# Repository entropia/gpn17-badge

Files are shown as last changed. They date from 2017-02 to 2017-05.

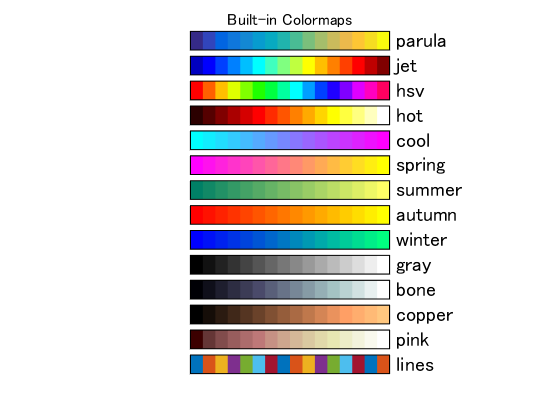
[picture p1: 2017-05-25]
examples/mandel/colormapGenerator/screenshot.jpg

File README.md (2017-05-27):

# GPN17 Badge
GPN Badge (Gulasch Push Notifications)

HowTo SetUp arduino:
- Install the newest arduino Version (tested with 1.8.2) from the [Arduino website](http://www.arduino.cc/en/main/software).
- Start Arduino and open Preferences window.
- Enter ```https://rawgit.com/entropia/gpn17-badge/master/arduino/package_gpnbadge_index.json``` into *Additional Board Manager URLs* field. You can add multiple URLs, separating them with commas.
- Open Boards Manager from Tools > Board menu and install *gpnbadge* platform (and don't forget to select the GPN Badge board from Tools > Board menu after installation).

To use multirom ability, please add 
```#include "rboot.h"```
to each of your sketches. This replaces the cache function in the libmain.a
Please note: For the moment, rboot is configured as following:

- 4 ROMs / 1MB each
- default boot ROM: 1 
- GPIO boot ROM: 0 (usually the ROM select app)

The GPIO boot is initialised by pulling GPIO16 high at POR. This is the same as pressing the center joystick of the GPN Badge at poweron. Other ROMs can be selected by using the rboot config library.

The patched arduino-esp8266 contains all tools for creating the usual eboot arduino roms, as well as rboot roms.
For this, in addition to esptool also Richard Burtons esptool2 ist downloaded and installed.

Have fun!

## In need for a example ROM?
Look for the "Sensors"-example.

## Beschreibung
Teilnehmerbadge mit vielen Funktionen für die GPN 17.

## Grafik-lib
https://github.com/entropia/Adafruit-GFX-Library

## Display-lib
https://github.com/antonxy/TFT_ILI9163C

By default this lib allocates a framebuffer.
If your rom is unstable because of little ram you can disable the framebuffer by commenting out `#define FRAMEBUFFER` in the `TFT_ILI9163C.h` file.
This should especially be done for the default rom.

## Arduino-lib
https://github.com/entropia/gpn17-badge-arduinolib

## UI-lib
https://github.com/entropia/gpn17-badge-ui

## Infrared-lib
https://github.com/markszabo/IRremoteESP8266

## Neopixel-lib
https://github.com/adafruit/Adafruit_NeoPixel

## Notification Server
https://github.com/entropia/gpn17-badge-notification-server

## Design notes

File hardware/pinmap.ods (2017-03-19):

GPIO | Function | V1.0 | V1.1 | V2.0
0 |  | BOOT / LCD DC | BOOT / LCD | BOOT / LCD DC
1 |  | UART TX | UART TX | UART TX
2 |  | WS2813 | USB DN | USB DN
3 |  | UART RX | UART RX | UART RX
4 |  | USB DN | WS2813 | WS2813
5 |  | USB DP | USB DP | USB DP
9 |  | LATCH | LATCH | I2C SDA
10 |  | LCD PWM | LCD PWM | I2C SCL
12 |  | SPI MISO | SPI MISO | SPI MISO (needed?) / BNO
13 |  | SPI MOSI | SPI MOSI | SPI MOSI
14 |  | SCP CLK | SPI CLK | SPI CLK
15 |  | LCD CS | LCD CS | LCD CS
16 |  | MPU6500 CS | MPU6500 CS | ROM Select
PCA9571
0 | MUX0
1 | MUX1
2 | MUX2
3 | VIBRATOR
4 | MQ3_en
5 | LCD_en
6 | Infrared_en
7

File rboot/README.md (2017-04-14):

GPN-Badge Port
--------------------------------------------------

HowTo:

1. Install arduino esp8266 IDE

2. Edit board.txt: Add attached config

3. Add LD scripts to
~/.arduino15/packages/esp8266/hardware/esp8266/2.3.0/tools/sdk/ld

4. Compile (don't upload) the sketch in the arduino IDE.
(to use bigflash, add both the big-flash.c as well as the rboot.h to the sketch)

5. Generate rboot compatible ROM
esptool2 -bin -boot2 /tmp/arduino_build_xxxxxx/sketch.ino.elf rom.bin .text .data .rodata

6. build rboot.bin (or use precompiled rboot.bin in /firmware)

7. flashing
esptool.py --port /dev/ttyUSB0 -b 921600 write_flash --flash_size 4MB --flash_mode dio 0x0 rboot.bin 0x02000 rom0.bin 0x102000 rom1.bin 0x202000 rom2.bin 0x302000 rom3.bin

rBoot - An open source boot loader for the ESP8266
--------------------------------------------------
by Richard A Burton, richardaburton@gmail.com
http://richard.burtons.org/

rBoot is designed to be a flexible open source boot loader, a replacement for
the binary blob supplied with the SDK. It has the following advantages over the
Espressif loader:

  - Open source (written in C).
  - Supports up to 256 roms.
  - Roms can be variable size.
  - Able to test multiple roms to find a valid backup (without resetting).
  - Flash layout can be changed on the fly (with care and appropriately linked
    rom images).
  - GPIO support for rom selection.
  - Wastes no stack space (SDK boot loader uses 144 bytes).
  - Documented config structure to allow easy editing from user code.
  - Can validate .irom0.text section with checksum.
  - Temporary next-boot rom selection.

Limitations
-----------
The ESP8266 can only map 8Mbits (1MB) of flash to memory, but which 8Mbits to
map is selectable. This allows individual roms to be up to 1MB in size, so long
as they do not straddle an 8Mbit boundary on the flash. This means you could
have four 1MB roms or 8 512KB roms on a 32Mbit flash (such as on the ESP-12), or
a combination. Note, however, that you could not have, for example, a 512KB rom
followed immediately by a 1MB rom because the 2nd rom would then straddle an
8MBit boundary. By default support for using more than the first 8Mbit of the
flash is disabled, because it requires several steps to get it working. See
below for instructions.

Building
--------
A Makefile is included, which should work with the gcc xtensa cross compiler.
There are two source files, the first is compiled and included as data in the
second. When run this code is copied to memory and executed (there is a good
reason for this, see my blog for an explanation). The make file will handle this
for you, but you'll need my esptool2 (see github).

To use the Makefile set `SDK_BASE` to point to the root of the Espressif SDK and
either set `XTENSA_BINDIR` to the gcc xtensa bin directory or include it in your
`PATH`. These can be set as environment variables or by editing the Makefile.

Two small assembler stub functions allow the bootloader to launch the user code
without reserving any space on the stack (while the SDK boot loader uses 144
bytes). This compiles fine with GCC, but if you use another compiler and it
will not compile/work for you then uncomment the `#define BOOT_NO_ASM` in `rboot.h`
to use a C version of these functions (this uses 32 bytes).

Tested with SDK v1.3 and GCC v4.8.2.

Installation
------------
Simply write rboot.bin to the first sector of the flash. Remember to set your
flash size correctly with your chosen flash tool (e.g. for esptool.py use the
`-fs` option). When run rBoot will create it's own config at the start of sector
two for a simple two rom system. You can can then write your two roms to flash
addresses `0x2000` and (half chip size + `0x2000`). E.g. for 8Mbit flash:
  `esptool.py write_flash -fs 8m 0x0000 rboot.bin 0x2000 user1.bin 0x82000 user2.bin`

Note: your device may need other options specified. E.g. The nodemcu devkit v1.0
(commonly, but incorrectly, sold as v2) also needs the `-fm dio` option.

For more interesting rom layouts you'll need to write an rBoot config sector
manually, see next step.

The two testload bin files can be flashed in place of normal user roms for
testing rBoot. You do not need these for normal use.

rBoot Config
------------

	typedef struct {
		uint8 magic;           // our magic
		uint8 version;         // config struct version
		uint8 mode;            // boot loader mode
		uint8 current_rom;     // currently selected rom
		uint8 gpio_rom;        // rom to use for gpio boot
		uint8 count;           // number of roms in use
		uint8 unused[2];       // padding
		uint32 roms[MAX_ROMS]; // flash addresses of the roms
	#ifdef BOOT_CONFIG_CHKSUM
		uint8 chksum;          // boot config chksum
	#endif
	} rboot_config;

Write a config structure as above to address `0x1000` on the flash. If you want
more than 4 roms (default) just increase MAX_ROMS when you compile rBoot.
Think about how you intend to layout your flash before you start!
Rom addresses must be sector aligned i.e start on a multiple of 4096.

  - `magic` should have value `0xe1` (defined as `BOOT_CONFIG_MAGIC`).
  - `version` is used in case the config structure changes after deployment. It is
    defined as `0x01` (`BOOT_CONFIG_VERSION`). I don't intend to increase this, but
    you should if you choose to reflash the bootloader after deployment and
    the config structure has changed.
  - `mode` can be `0x00` (`MODE_STANDARD`) or `0x01` (`MODE_GPIO_ROM`). See below for an
    explanation of `MODE_GPIO_ROM`. There is also an optional extra mode flag `0x04`
    (`MODE_GPIO_ERASES_SDKCONFIG`), see below for details.
  - `current_rom` is the rom to boot, numbered `0` to `count-1`.
  - `gpio_rom` is the rom to boot when the GPIO is triggered at boot.
  - `count` is the number of roms available (may be less than `MAX_ROMS`, but not
    more).
  - `unused[2]` is padding so the `uint32` rom addresses are 4 bytes aligned.
  - `roms` is the array of flash address for the roms. The default generated
    config will contain two entries: `0x00002000` and `0x00082000`.
  - `chksum` (if enabled, not by deafult) should be the xor of `0xef` followed by
    each of the bytes of the config structure up to (but obviously not
    including) the chksum byte itself.

Default config
--------------
A default config sector will be created on boot if one does not exists, or if an
existing config is corrupted, and the default rom will be set to rom 0. If you
want to have a very customised config for which the default would not be
suitable, you can override the implementation in the `rboot.h` header file. See the
comments and example code in `rboot.h` for more information.

GPIO boot mode
--------------
If rBoot is compiled with `BOOT_GPIO_ENABLED` set in `rboot.h` (or
`RBOOT_GPIO_ENABLED` set in the Makefile), then GPIO boot functionality will be
included in the rBoot binary. The feature can then be enabled by setting the
rboot_config `mode` field to `MODE_GPIO_ROM`. You must also set `gpio_rom` in the
config to indicate which rom to boot when the GPIO is activated at boot.

If the GPIO input pin reads high at boot then rBoot will start the currently
selected normal or temp rom (as appropriate). However if the GPIO is pulled low
then the rom indicated in config option `gpio_rom` is started instead.

The default GPIO is 16, but this can be overriden in the Makefile
(`RBOOT_GPIO_NUMBER`) or `rboot.h` (`BOOT_GPIO_NUM`). If GPIOs other than 16 are used,
the internal pullup resistor is enabled before the pin is read and disabled
immediately afterwards. For pins that default on reset to configuration other
than GPIO input, the pin mode is changed to input when reading but changed back
before rboot continues.

After a GPIO boot the `current_rom` field will be updated in the config, so the
GPIO booted rom should change this again if required.

GPIO boot skip mode
-------------------
If rBoot is compiled with `BOOT_GPIO_SKIP_ENABLED` set in `rboot.h` (or
`RBOOT_GPIO_SKIP_ENABLED` set in the Makefile), then a GPIO can be used to skip
to the next rom at boot. The feature must then be enabled by setting the
rboot_config 'mode' field to `MODE_GPIO_SKIP`. This means you do not need to have
a dedicated GPIO boot rom. If you have a rom that is technically good (valid
checksum, etc.) but has operational problems, e.g. wifi doesn't work or it
crashes on boot, rBoot will not be able to detect that and switch rom
automatically. In this scenario rebooting the device while pulling the GPIO low
will force rBoot to skip this rom and try the next one instead. In a simple two
rom setup this simply toggles booting of the other rom.

`RBOOT_GPIO_SKIP_ENABLED` and `RBOOT_GPIO_ENABLED` cannot be used at the same time.
`BOOT_GPIO_NUM` is used to select the GPIO pin, as with `RBOOT_GPIO_ENABLED`.

Erasing SDK configuration on GPIO boot (rom or skip mode)
---------------------------------------------------------
If you set the `MODE_GPIO_ERASES_SDKCONFIG` flag in the configuration like this:
  `conf.mode = MODE_GPIO_ROM|MODE_GPIO_ERASES_SDKCONFIG`;
then a GPIO boot will also the erase the Espressif SDK persistent settings
store in the final 16KB of flash. This includes removing calibration
constants, saved SSIDs, etc.

Note that `MODE_GPIO_ERASES_SDKCONFIG` is a flag, so it has to be set as
well as `MODE_GPIO_ROM` to take effect.

Linking user code
-----------------
Each rom will need to be linked with an appropriate linker file, specifying
where it will reside on the flash. If you are only flashing one rom to multiple
places on the flash it must be linked multiple times to produce the set of rom
images. This is the same as with the SDK loader.

Because there are endless possibilities for layout with this loader I don't
supply sample linker files. Instead I'll tell you how to make them.

For each rom slot on the flash take a copy of the `eagle.app.v6.ld` linker script
from the sdk. You then need to modify just one line in it for each rom:
  `irom0_0_seg :                         org = 0x40240000, len = 0x3C000`

Change the org address to be `0x40200000` (base memory mapped location of the
flash) + flash address + `0x10` (offset of data after the header).
The logical place for your first rom is the third sector, address `0x2000`.
  `0x40200000 + 0x2000 + 0x10 = 0x40202010`
If you use the default generated config the loader will expect to find the
second rom at flash address half-chip-size + `0x2000` (e.g. `0x82000` on an 8MBit
flash) so the `irom0_0_seg` should be:
  `0x40200000 + 0x82000 + 0x10 = 0x40282010`
Due to the limitation of mapped flash (max 8MBit) if you use a larger chip and
do not have big flash support enabled the second rom in the default config will
still be placed at `0x082000`, not truly half-chip-size + `0x2000`.
Ideally you should also adjust the len to help detect over sized sections at
link time, but more important is the overall size of the rom which you need to
ensure fits in the space you have allocated for it in your flash layout plan.

Then simply compile and link as you would normally for OTA updates with the SDK
boot loader, except using the linker scripts you've just prepared rather than
the ones supplied with the SDK. Remember when building roms to create them as
'new' type roms (for use with SDK boot loader v1.2+). Or if using my esptool2
use the `-boot2` option. Note: the test loads included with rBoot are built with
`-boot0` because they do not contain a `.irom0.text` section (and so the value of
`irom0_0_seg` in the linker file is irrelevant to them) but 'normal' user apps
always do.

irom checksum
-------------
The SDK boot loader checksum only covers sections loaded into ram (data and some
code). Most of the SDK and user code remains on the flash and that is not
included in the checksum. This means you could attempt to boot a corrupt rom
and, because it looks ok to the boot loader, there will be no attempt to switch
to a backup rom. rBoot improves on this by allowing the `.irom0.text` section to
be included in the checksum. To enable this uncomment `#define BOOT_IROM_CHKSUM`
in `rboot.h` and build your roms with esptool2 using the `-iromchksum` option.

Big flash support
-----------------
This only needs to be enabled if you wish to be able to memory map more than the
first 8MBit of the flash. Note you can still only map 8Mbit at a time. Use this
if you want to have multiple 1MB roms, or more smaller roms than will fit in
8Mbits. If you have a large flash but only need, for example, two 512KB roms you
do not need to enable this mode.

Support in rBoot is enabled by uncommenting the `#define BOOT_BIG_FLASH` in
`rboot.h`.

Thinking about your linker files is either simpler or more complicated,
depending on your usage of the flash. If you intend to use multiple 1MB roms you
will only need one linker file and you only need to link once for OTA updates.
Although when you perform an OTA update the rom will be written to a different
position on the flash, each 8Mbit of flash is mapped (separately) to `0x40200000`.
So when any given rom is run the code will appear at the same place in memory
regardless of where it is on the flash. Your base address for the linker would
be `0x40202010`. (Actually all but the first rom could base at `0x40200010` (because
they don't need to leave space for rBoot and config) but then you're just making
it more complicated again!)

If you wanted eight 512KB roms you would need two linker files - one for the
first half of any given 8Mbits of flash and another for the second half. Just
remember you are really laying out within a single 8MBit area, which can then be
replicated multiple times on the flash.

Now the clever bit - rBoot needs to hijack the memory mapping code to select
which 8Mbits gets mapped. There is no API for this, but we can override the SDK
function. First we need to slightly modify the SDK library `libmain.a`, like so:

	xtensa-lx106-elf-objcopy -W Cache_Read_Enable_New libmain.a libmain2.a

This produces a version of libmain with a 'weakened' `Cache_Read_Enable_New`
function, which we can then override with our own. Modify your Makefile to link
against the library `main2` instead of `main`.

Next add `rboot-bigflash.c` (from the `appcode` directory) & `rboot.h` to your 
project - this adds the replacement `Cache_Read_Enable_New` to your code.

Getting gcc to apply the override correctly can be slightly tricky (I'm not sure
why, it shouldn't be). One option is to add `-u Cache_Read_Enable_New` to your
`LD_FLAGS` and change the order of objects on the LD command so your `objects/.a`
file is before the libraries. Another way that seems easier was to `#include
rboot-bigflash.c` into the main .c file, rather than compiling it to a separate
object file. I can't make any sense of that, but I suggest you uncomment the
message in the `Cache_Read_Enable_New` function when you first build with it, to
make sure you are getting your version into the rom.

Now when rBoot starts your rom, the SDK code linked in it that normally performs
the memory mapping will delegate part of that task to rBoot code (linked in your
rom, not in rBoot itself) to choose which part of the flash to map.

Temporary boot option and rBoot<-->app communication
----------------------------------------------------
To enable communication between rBoot and your app you should enable the
`BOOT_RTC_ENABLED` option in `rboot.h`. rBoot will then use the RTC data area to
pass a structure with boot information which can be read by the app. This will
allow the app to determine the boot mode (normal, temporary or GPIO) and the
booted rom (even if it is a tempoary boot). Your app can also update this
structure to communicate with rBoot when the device is next rebooted, e.g. to
instruct it to temporarily boot a different rom to the one saved in the config.
See the api documentation and/or the rBoot sample project for more details.
Note: the message "don't use rtc mem data", commonly seen on startup, comes from
the sdk and is not related to this rBoot feature.

Integration into other frameworks
---------------------------------
If you wish to integrate rBoot into a development framework (e.g. Sming) you
can set the define `RBOOT_INTEGRATION` and at compile time the file
`rboot-integration.h` will be included into the source. This should allow you to
set some platform specific options without having to modify the source of rBoot
which makes it easier to integrate and maintain.

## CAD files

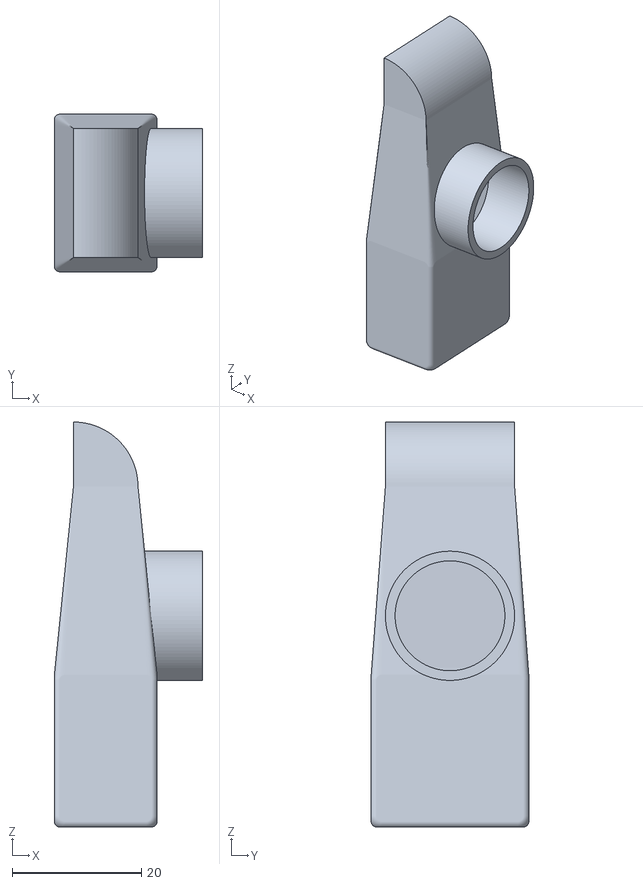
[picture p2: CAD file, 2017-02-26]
hardware/3D/CAD/Alkoholsensor/Alkoholsensor.stl
22.9 x 24.4 x 62.7

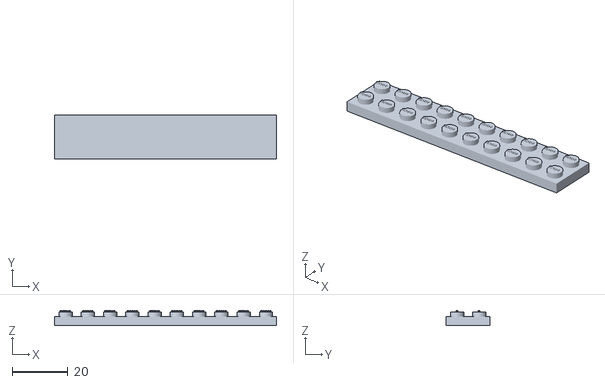
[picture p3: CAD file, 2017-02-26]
hardware/3D/CAD/Baukloetzchen/baukloetzchen_single.stl
79.8 x 15.8 x 5.50

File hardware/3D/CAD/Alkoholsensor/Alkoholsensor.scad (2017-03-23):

// set quality to 20 for working with the model, 200 for the export
quality = 200;
// thickness of the walls at the thinnest wall
thickness = 1.5;
// Some Text :3
text = "GPN17";
font = "DejaVu Serif";
textsize = 5;
// some perimeters, diameter of the sensor, heigth of the plug and length of the blowing tube ( length of the mouthpiece and the exhaust will be added )
diameter = 17.3;
width = diameter + thickness * 2;
height_sens = 3;
height = 10 + thickness + 2;
length = 30;
tube_offset = -3; 
//perimeters for the mouthpiece
m_width = 13;
m_height = 7;
m_lenght = 20;
m_d = 3;

//rotate the object for 3D-printing
rotate([0,90,0])

difference(){
    union(){

        // sensor cylinder
        translate([tube_offset,0,height/2])
        cylinder(h = height_sens, d = diameter + thickness * 2, $fn = quality);
        
        // main shaft and mouth piece 2
        hull(){
            translate([length/2,0,0])
            mouthpiece2();
            cube([length,width,height],center = true);
        }
        
        //exhaust
        translate([ -length/2, diameter/2+thickness, -height/2])
        rotate([90,90,0])
        mirror([1,0,0])
        exhaust(width,height,90,thickness);
        
        //mouthpiece2
        translate([length/2,0,0])
        mouthpiece1();
        
        // Text 
        translate([ length/2-3.5,-textsize/2,-height/2])
        rotate([180,0,180])
        #linear_extrude(0.5)
        text(text = str(text), font = font, size = textsize);
    }
    union(){
        
        // sensorcylinder
        translate([tube_offset,0,0]) 
        cylinder(h = height+height/2, d = diameter, $fn = quality);
        
        //inner cube
        translate([length/2,0,0])
        cube([6,m_width-thickness*2,height-thickness*2],center = true);
        
        // main shaft
        cube([length,width-thickness*2,height-thickness*2],center = true);
    }
}
/////////////////////////////////////////////////////////////////
/////////////////// Modules go here ///////////////////
/////////////////////////////////////////////////////////////////
module mouthpiece1(){
    difference(){
        union(){
            // outer cube
            translate([m_lenght/2,0.5,-0.5])
            minkowski(){
                minkowski(){
                    minkowski(){
                        cube([m_lenght-m_d*2,m_width-m_d,m_height-m_d],center = true);
                            cylinder(h=1,d=m_d,$fn=quality);
                        }
                    rotate([90,0,0])
                    cylinder(h=1,d=m_d,$fn=quality);
                }
                rotate([0,90,0])
                cylinder(h=1,d=m_d,$fn=quality);
            }
        }
        union(){
            //inner section
            hull(){
                translate([m_lenght,0,0])
                minkowski(){
                    cube([1.1,m_width-2,m_height-1.5],center = true);
                    rotate([0,90,0])
                    cylinder(h=1,d=2,$fn=quality);            
                }
                translate([m_lenght/2,0,0])
                minkowski(){
                    cube([0.5,m_width/4,m_height/4],center = true);
                    rotate([0,90,0])
                    cylinder(h=1,d=2,$fn=quality);            
                }
            }
            hull(){
                translate([m_lenght/2,0,0])
                minkowski(){
                    cube([0.5,m_width/4,m_height/4],center = true);
                    rotate([0,90,0])
                    cylinder(h=1,d=2,$fn=quality);            
                }
                translate([2,0,0])
                cube([1,m_width-thickness*2+0.5,height-thickness*2+0.25],center = true);
                }
            cube([3,m_width*1.5,m_height*1.5],center = true); 
        }
    }
}

module mouthpiece2(){
    difference(){
        union(){
            // outer Section
            translate([m_lenght/2,0.5,-0.5])
            minkowski(){
                minkowski(){
                    minkowski(){
                        cube([m_lenght-m_d*2,m_width-m_d,m_height-m_d],center = true);
                            cylinder(h=1,d=m_d,$fn=quality);
                        }
                    rotate([90,0,0])
                    cylinder(h=1,d=m_d,$fn=quality);
                }
                rotate([0,90,0])
                cylinder(h=1,d=m_d,$fn=quality);
            }
        }
        union(){
            // cutaway
            translate([0,0,0])
            cube([6,m_width-thickness*2,height-thickness*2],center = true);
            translate([m_lenght/2+3,0,0])
            cube([m_lenght,m_width*1.5,m_height*2],center = true); 
        }
    }
}


module exhaust(w,h,a,t){
    difference(){
        union(){
            // outer ring
            cylinder(r=h,h=w,$fn=quality);
        }
        union(){
            // cut sections
            translate([-h,0,0])
            cube([h*2,h,w]);
            translate([0,h,0])
            rotate([0,0,270-a])
            cube([h,h*2,w]);
            // hollow section
            translate([0,0,t])
            cylinder(r=h-t,h=w-t*2,$fn=quality);
        }
    }
    
    difference(){
        union(){
            // inner ring
           cylinder(r=t,h=w,$fn=quality);
        }
        union(){
            // cutting sections            
            translate([-h,0,0])
            cube([h*2,h,w]);
            translate([0,h,0])
            rotate([0,0,270-a])
            cube([h,h*2,w]);  
        }
    }
}

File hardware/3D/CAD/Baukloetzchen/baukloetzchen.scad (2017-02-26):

text = "GPN17";
font = "DejaVu Serif";
//use "baukloetzchen(x,y)" to create a single height "baukloetzchen"
color("red")
baukloetzchen(20,2);

color("red")
translate([0,-100,0])

baukloetzchen(10,2);

// the pcb-method creates a shape, which looks like the pcb
translate([0,0,0])
pcb(4,19,3);

module pcb(x = 4 , y = 4,offset = 2){
    difference(){
        union(){
            hull(){
                translate([0,0,4])
                cube([8*x-0.2,8*y/3-0.2,1.6],center = true);
                translate([0,-8*y/1.8/2-0.2,4])
                cube([8*x/2-0.2,8*y/1.8-0.2,1.6],center = true);
            }
            translate([0,((-8*y-0.2)/2)+8*offset,4])
            cube([8*x/2-0.2,8*y-0.2,1.6],center = true);
        }
        union(){
        }
    }
}

module baukloetzchen(x = 1,y = 1){
    difference(){
        union(){
            translate([0,0,1.6])
            cube([8*x-0.2,8*y-0.2,3.2],center = true);
            for(i = [0:8:8*x-1]){
                for(j = [0:8:8*y-1]){
                    translate([i+4-(8*x-0.2)/2,j+4-(8*y-0.2)/2,3.2])
                    cylinder(h=1.7,d=4.8,$fn=40);
                    translate([i+4-(8*x-0.2)/2-2,j+4-(8*y-0.2)/2-0.5,5])
                    linear_extrude(0.5)
                    text(text = str(text), font = font, size = 0.8);
                }
            }
        }
        union(){
            translate([0,0,1.59])
            cube([8*x-1.2*2,8*y-1.2*2,3.2],center = true);
        }
    }
}

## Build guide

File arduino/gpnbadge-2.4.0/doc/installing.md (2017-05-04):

---
title: Installation
---

## Boards Manager ##

This is the suggested installation method for end users.

### Prerequisites
- Arduino 1.6.8, get it from [Arduino website](https://www.arduino.cc/en/Main/OldSoftwareReleases#previous).
- Internet connection

### Instructions
- Start Arduino and open Preferences window.
- Enter ```http://arduino.esp8266.com/stable/package_esp8266com_index.json``` into *Additional Board Manager URLs* field. You can add multiple URLs, separating them with commas.
- Open Boards Manager from Tools > Board menu and find *esp8266* platform.
- Select the version you need from a drop-down box.
- Click *install* button.
- Don't forget to select your ESP8266 board from Tools > Board menu after installation.

You may optionally use *staging* boards manager package link:
`http://arduino.esp8266.com/staging/package_esp8266com_index.json`. This may contain some new features, but at the same time, some things might be broken.

## Using git version

This is the suggested installation method for contributors and library developers.

### Prerequisites

- Arduino 1.6.8 (or newer, if you know what you are doing)
- git
- python 2.7
- terminal, console, or command prompt (depending on you OS)
- Internet connection

### Instructions

- Open the console and go to Arduino directory. This can be either your *sketchbook* directory (usually `<Documents>/Arduino`), or the directory of Arduino application itself, the choice is up to you.
- Clone this repository into hardware/esp8266com/esp8266 directory. Alternatively, clone it elsewhere and create a symlink, if your OS supports them.

    ```bash
    cd hardware
    mkdir esp8266com
    cd esp8266com
    git clone https://github.com/esp8266/Arduino.git esp8266
    ```
    You should end up with the following directory structure:

    ```bash
    Arduino
    |
    --- hardware
        |
        --- esp8266com
            |
            --- esp8266
                |
                --- bootloaders
                --- cores
                --- doc
                --- libraries
                --- package
                --- tests
                --- tools
                --- variants
                --- platform.txt
                --- programmers.txt
                --- README.md
                --- boards.txt
                --- LICENSE
    ```

- Download binary tools

    ```bash
    cd esp8266/tools
    python get.py
    ```

- Restart Arduino

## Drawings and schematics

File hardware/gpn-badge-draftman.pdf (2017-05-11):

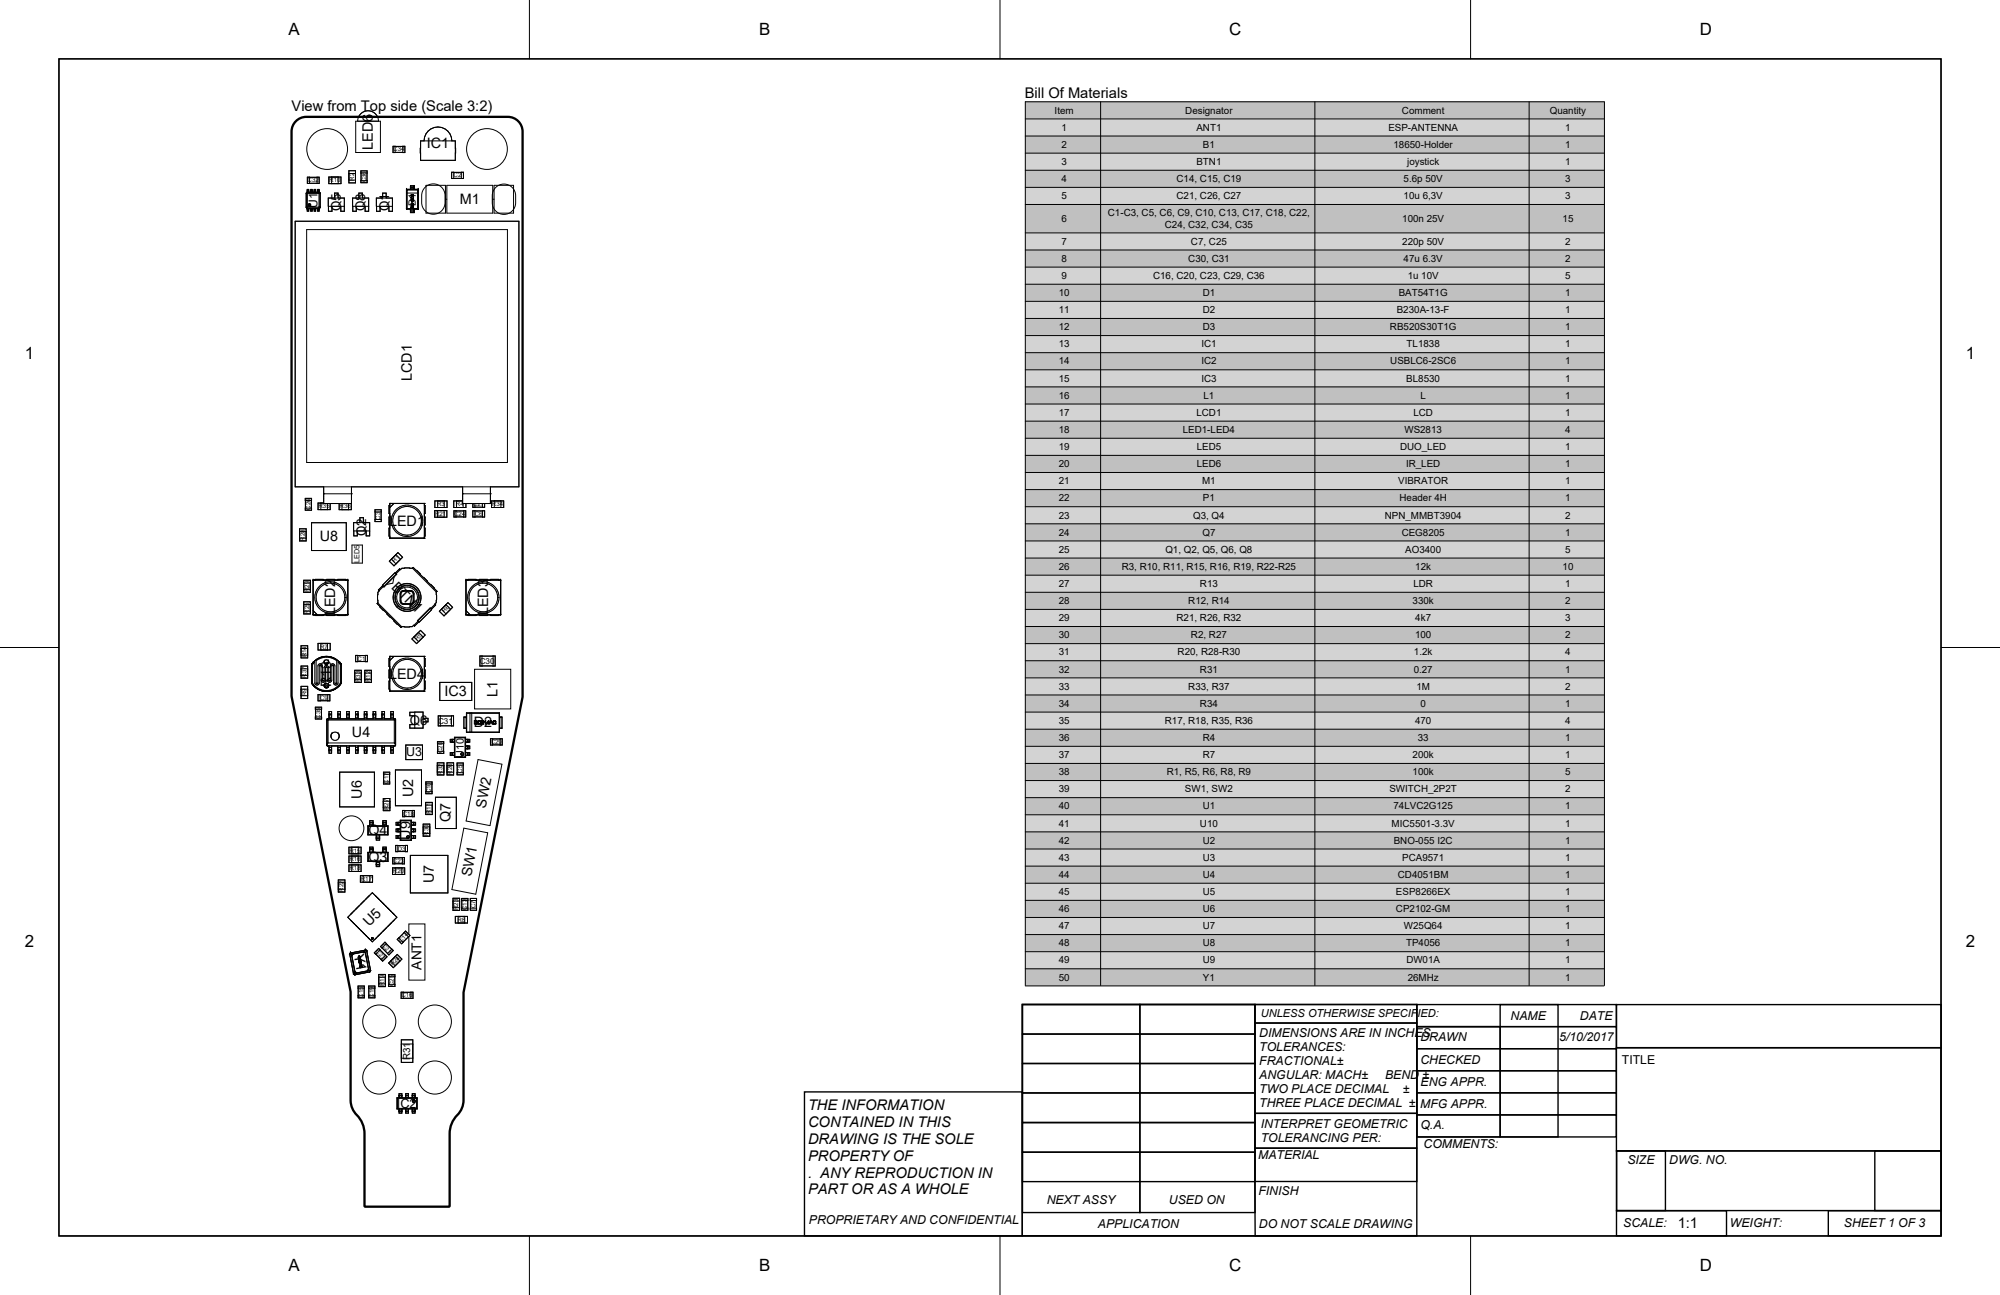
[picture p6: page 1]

View from Top side (Scale 3:2)

Item123456789 | BTN1 | joystick

B1 | 18650-Holder | Quantity 11133
Designator | Comment
ANT1 | ESP-ANTENNA

C7, C25 | 220p 50V
C30, C31 | 47u 6.3V

10 | D1 | BAT54T1G
11 | D2 | B230A-13-F

13 | IC1 | TL1838
14 | IC2 | USBLC6-2SC6
15 | IC3 | BL8530 L
16 | L1
17 | LCD1 | LCD
18 | LED1-LED4 | WS2813
19 | LED5 | DUO_LED
20 | LED6 | IR_LED
21 | M1 | VIBRATOR
22 | P1 | Header 4H

24 | Q7 | CEG8205
25 | Q1, Q2, Q5, Q6, Q8 | AO3400
34 | R34 | | 10123241214115211111111111
26 | R3, R10, R11, R15, R16, R19, R22-R25 | 12k
27 | R13 | LDR
28 | R12, R14 | 330k
29 | R21, R26, R32 | 4k7
30 | R2, R27 | 100
31 | R20, R28-R30 | 1.2k
32 | R31 | 0.27
33 | R33, R37 | 1M0

35 | R17, R18, R35, R36 | 470
36 | R4 | 33
37 | R7 | 200k
38 | R1, R5, R6, R8, R9 | 100k
39 | SW1, SW2 | SWITCH_2P2T
40 | U1 | 74LVC2G125
41 | U10 | MIC5501-3.3V
42 | U2 | BNO-055 I2C

45 | U5 | ESP8266EX
46 | U6 | CP2102-GM
47 | U7 | W25Q64
48 | U8 | TP4056
49 | U9 | DW01A
50 | Y1 | 26MHz

UNLESS OTHERWISE SPECIFIED:
DIMENSIONS ARE IN INCHES
TOLERANCES:
FRACTIONAL±
TWO PLACE DECIMAL ±
THREE PLACE DECIMAL ±
INTERPRET GEOMETRIC
TOLERANCING PER:
MATERIAL

THE INFORMATION
CONTAINED IN THIS
DRAWING IS THE SOLE
PROPERTY OF
. ANY REPRODUCTION IN
PART OR AS A WHOLE

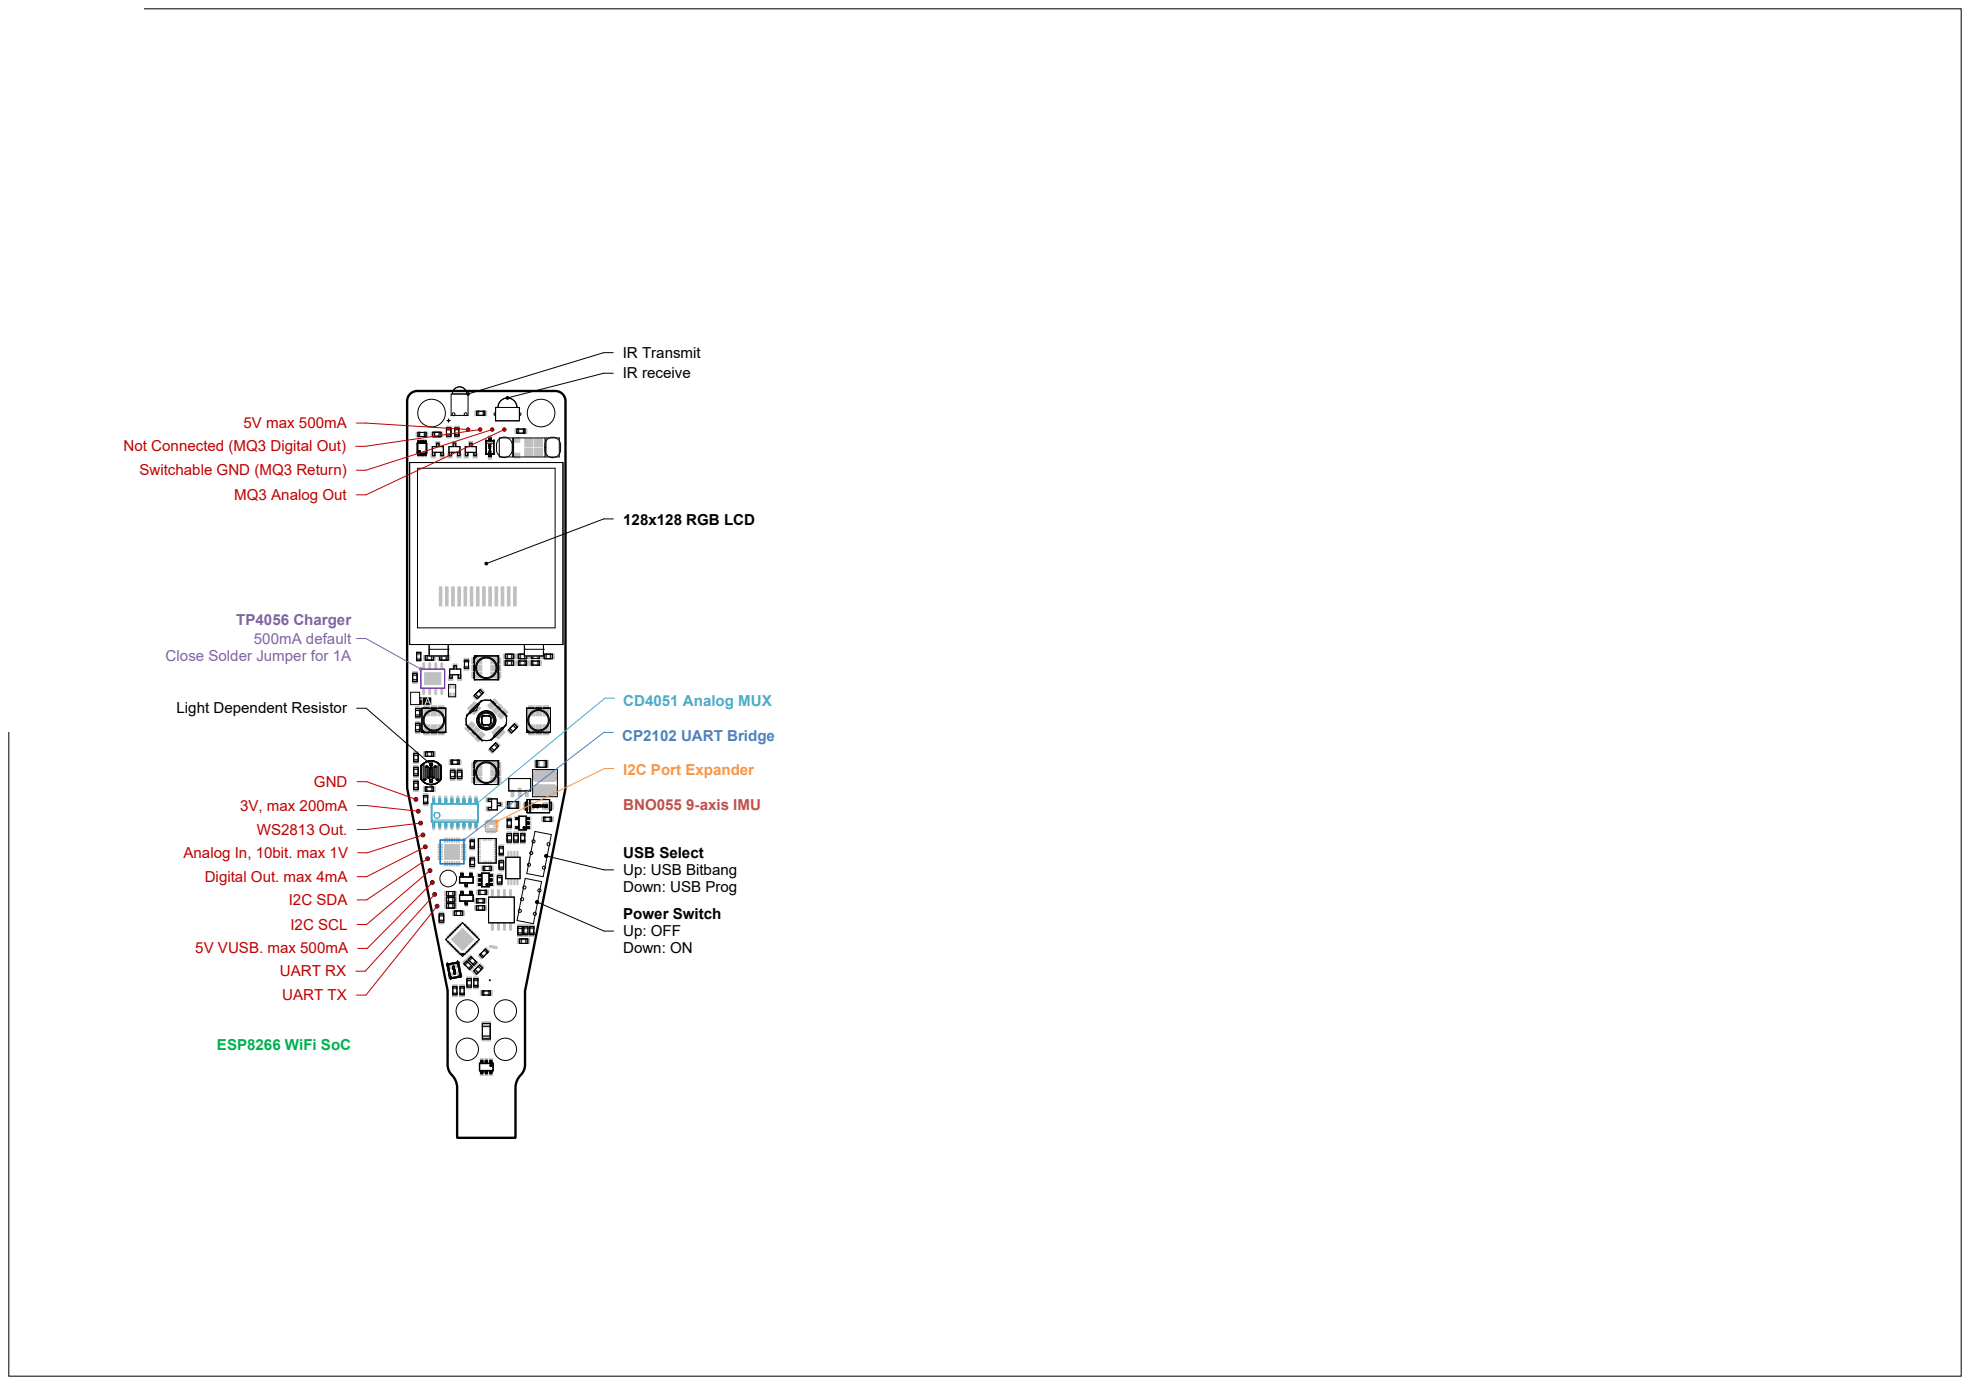
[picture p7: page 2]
IR receive; IR Transmit; 128x128 RGB LCD; BNO055 9-axis IMU; I2C Port Expander; CP2102 UART Bridge; CD4051 Analog MUX; ESP8266 WiFi SoC; GND 3V, max 200mA WS2813 Out.; I2C SDA I2C SCL 5V VUSB. max 500mA UART RX UART TX; TP4056 Charger 500mA default; 5V max 500mA; MQ3 Analog Out

Not Connected (MQ3 Digital Out)
Switchable GND (MQ3 Return)

Close Solder Jumper for 1A

Light Dependent Resistor

Analog In, 10bit. max 1V
Digital Out. max 4mA

USB Select
Up: USB Bitbang
Down: USB Prog
Power Switch
Up: OFF
Down: ON

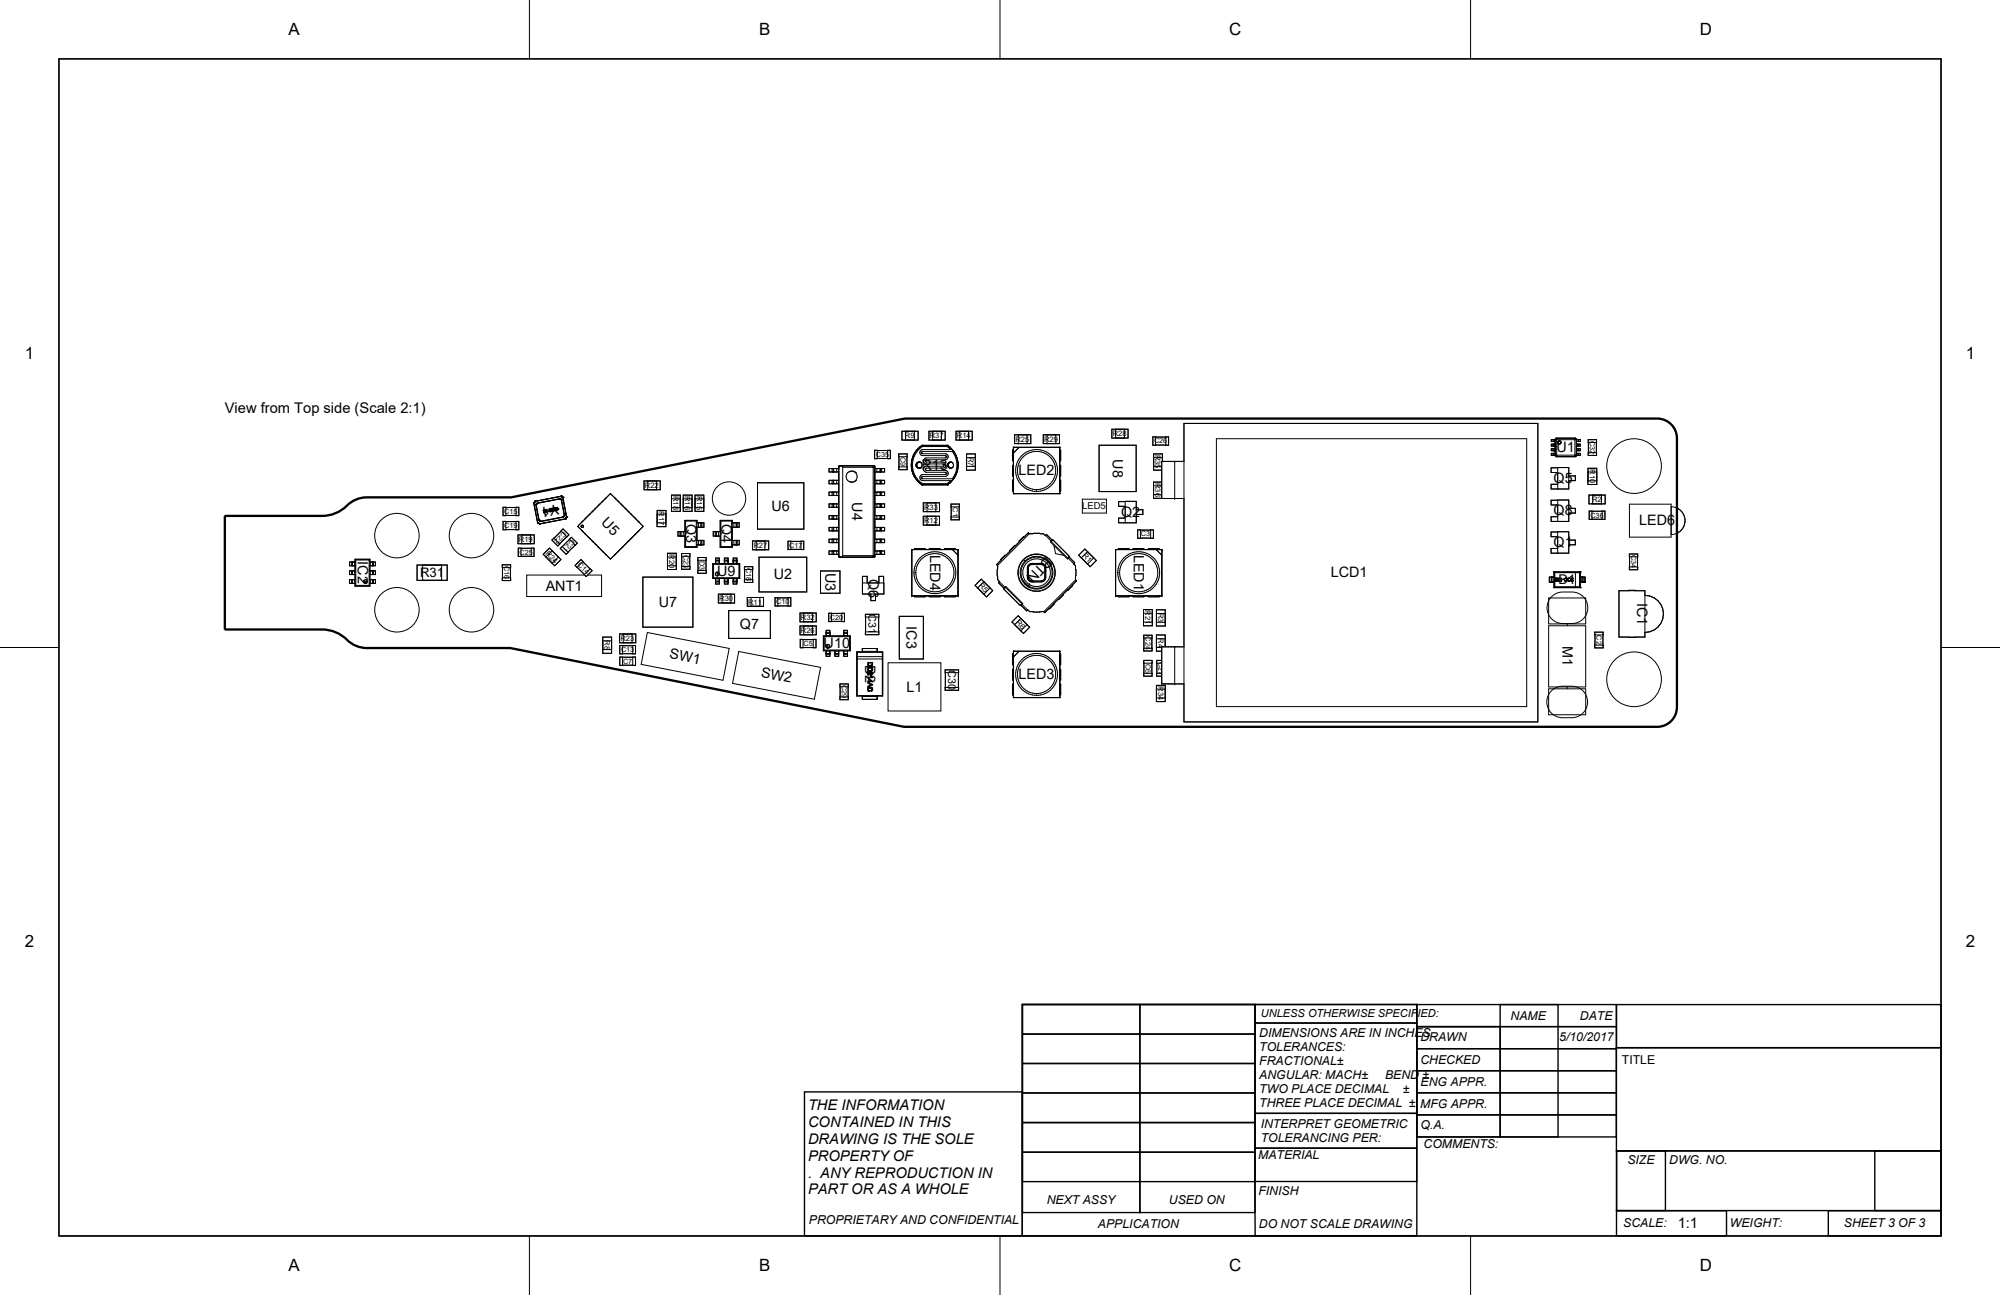
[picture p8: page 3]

View from Top side (Scale 2:1)

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

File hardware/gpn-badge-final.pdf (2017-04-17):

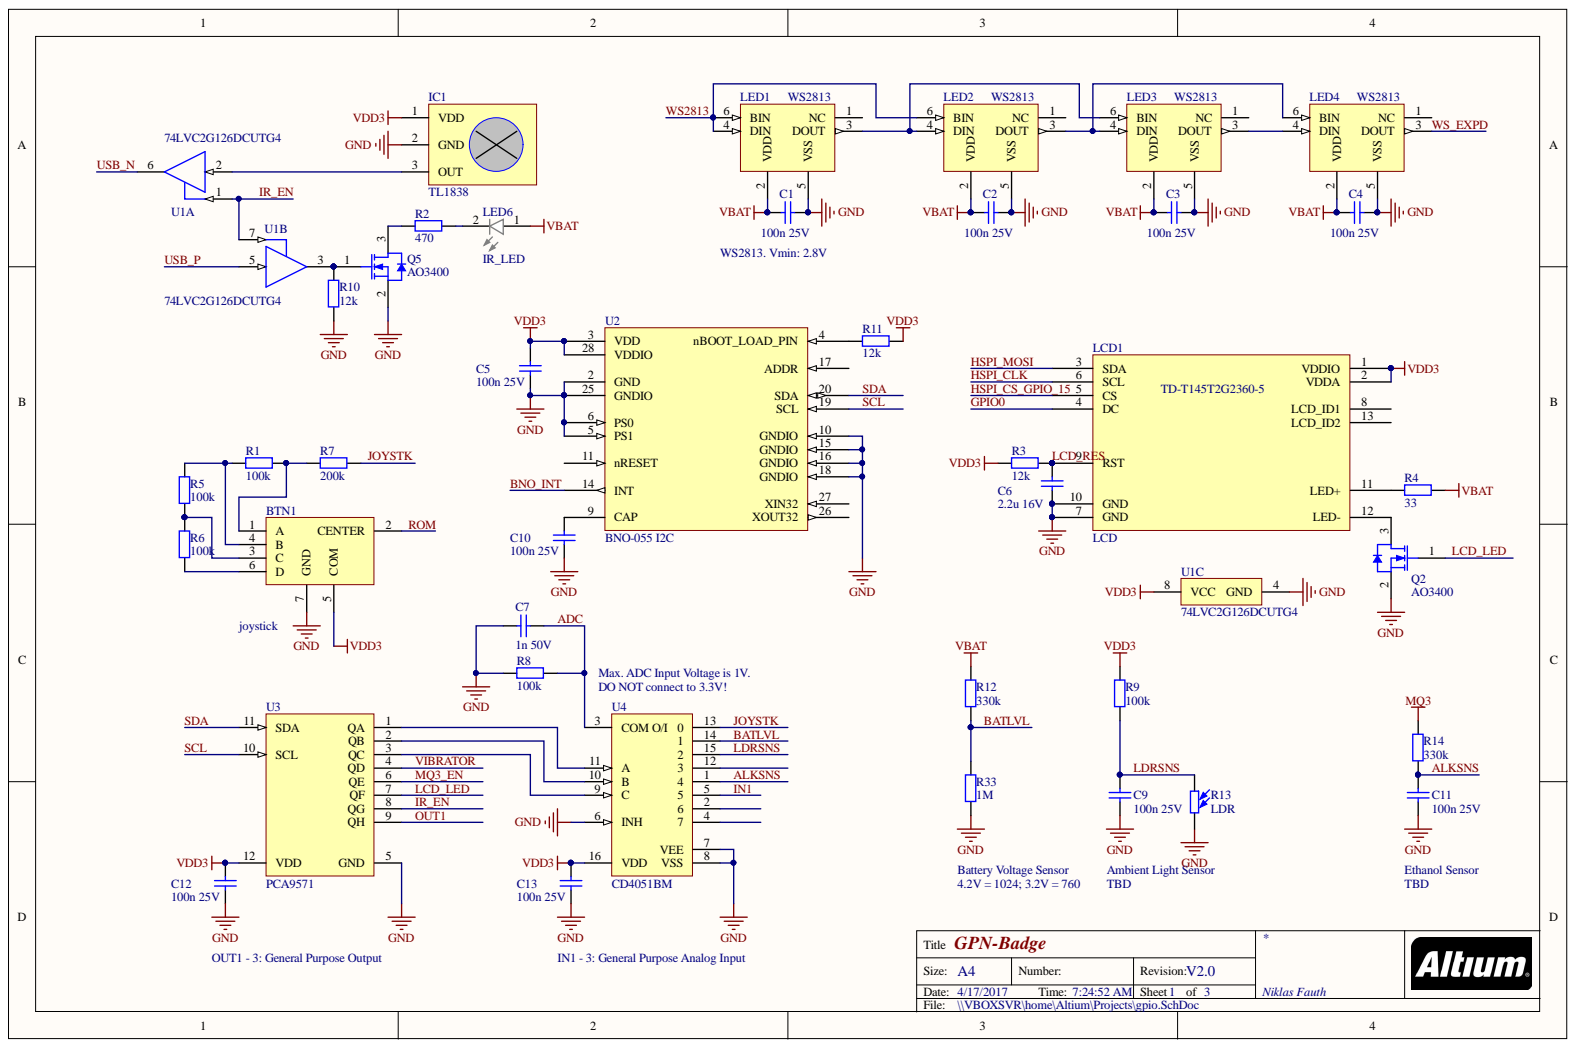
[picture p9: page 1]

Max. ADC Input Voltage is 1V.
COM O/I 3

GPN-Badge Title | * Niklas Fauth

Size: A4 | Number: | Revision: V2.0

Date: 4/17/2017 Time: 7:24:52 AM | | Sheet 1 of 3
File: \\VBOXSVR\home\Altium\Projects\gpio.SchDoc

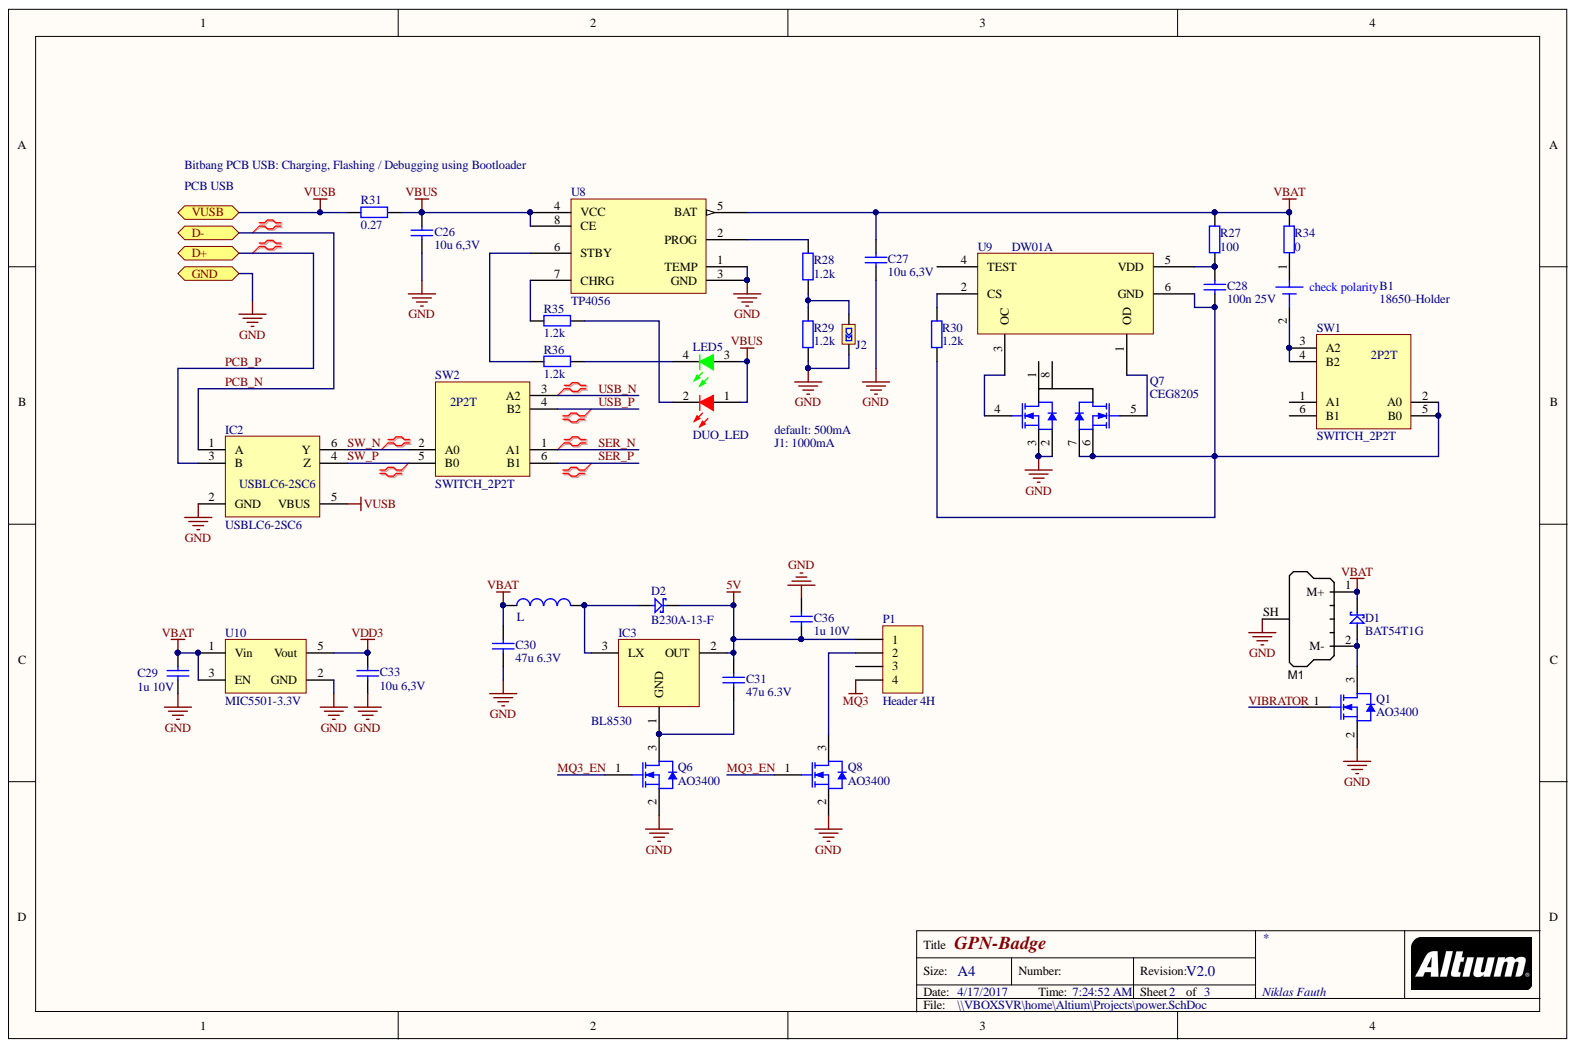
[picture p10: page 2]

Bitbang PCB USB: Charging, Flashing / Debugging using Bootloader
VBAT PCB USB

GPN-Badge Title | * Niklas Fauth

Size: A4 | Number: | Revision: V2.0

Date: 4/17/2017 Time: 7:24:52 AM | | Sheet 2 of 3
File: \\VBOXSVR\home\Altium\Projects\power.SchDoc

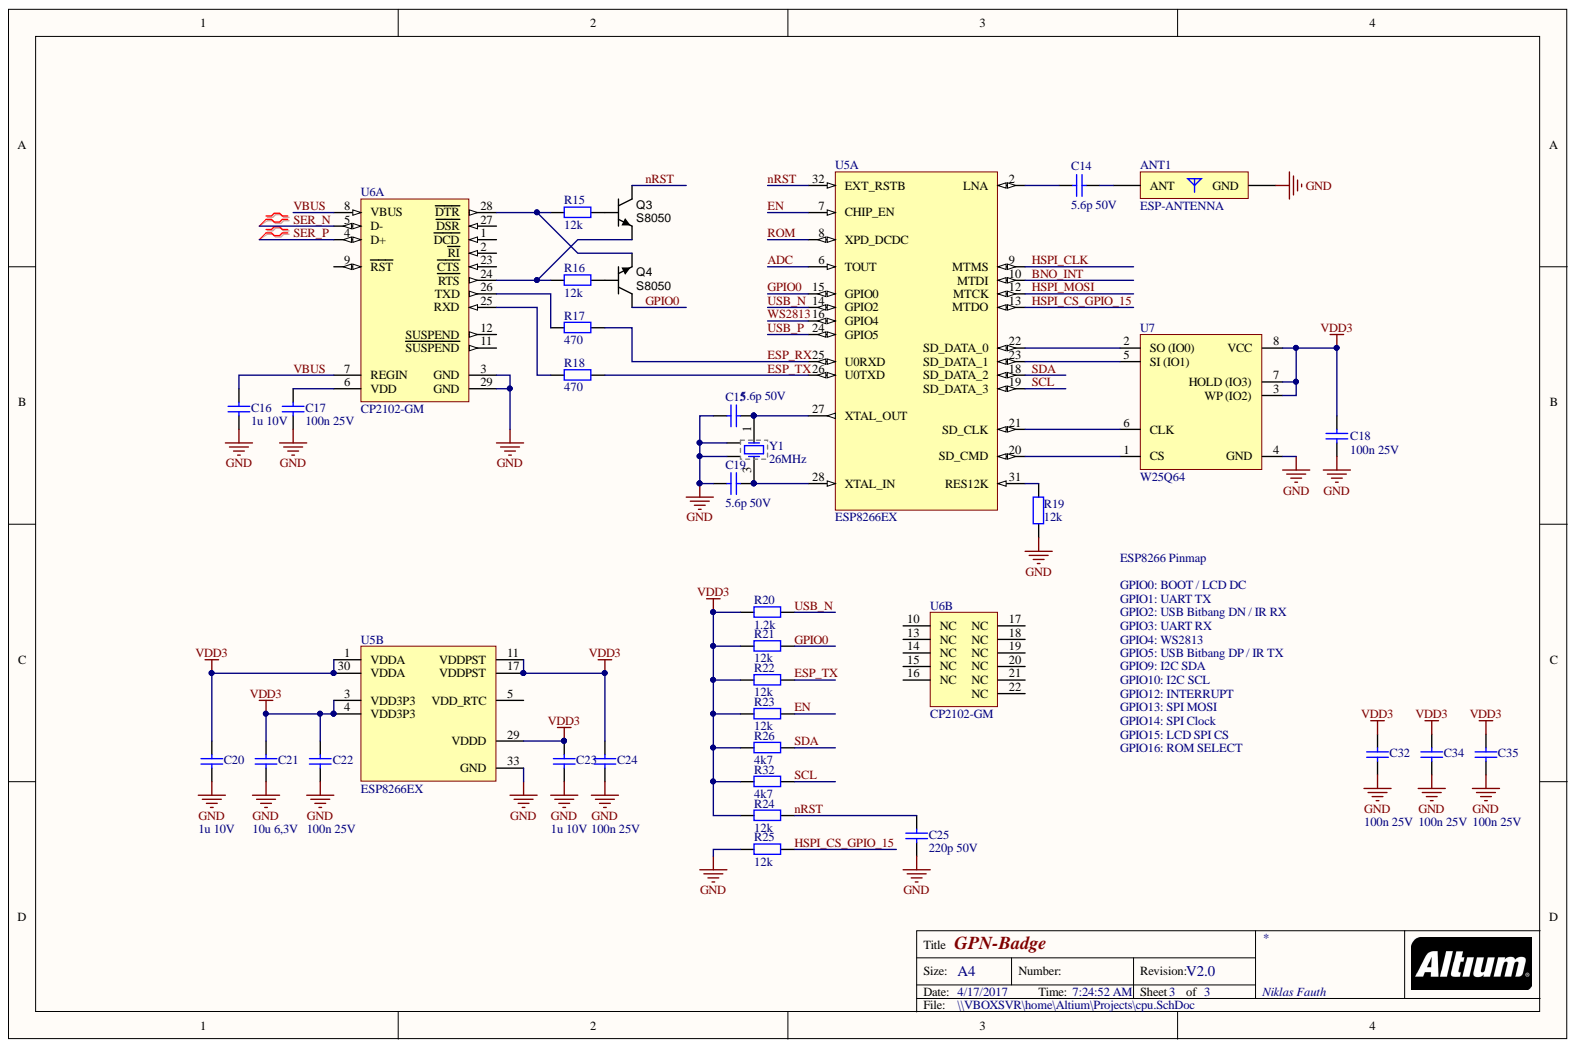
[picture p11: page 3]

GPN-Badge | * Niklas Fauth

A 4 | Numbe r : | R evision: V 2.0

D ate : 4/17/2017 Time : 7:24:52 AM | | She e t 3 of 3
File : \\V B O X S V R\home\Altium\P roje cts\cpu. S chDoc

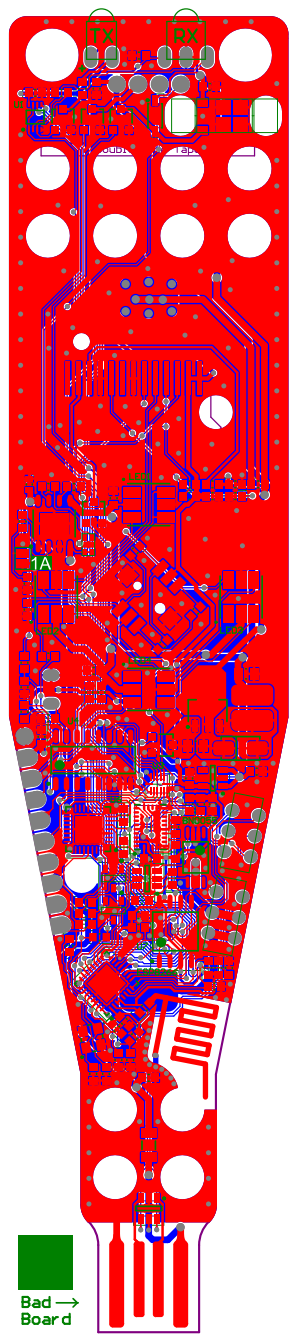
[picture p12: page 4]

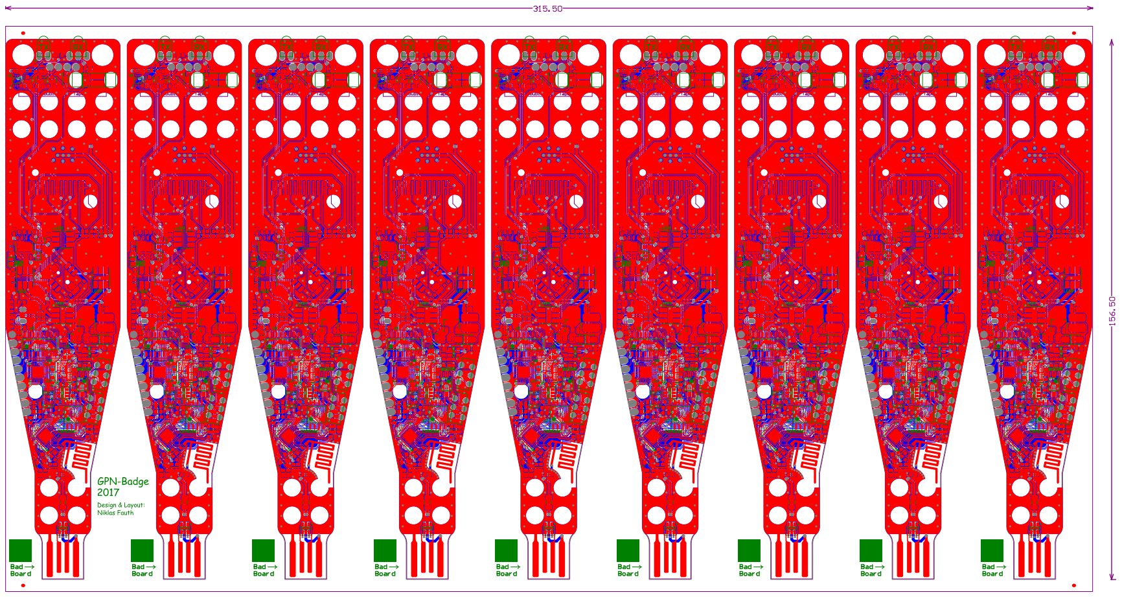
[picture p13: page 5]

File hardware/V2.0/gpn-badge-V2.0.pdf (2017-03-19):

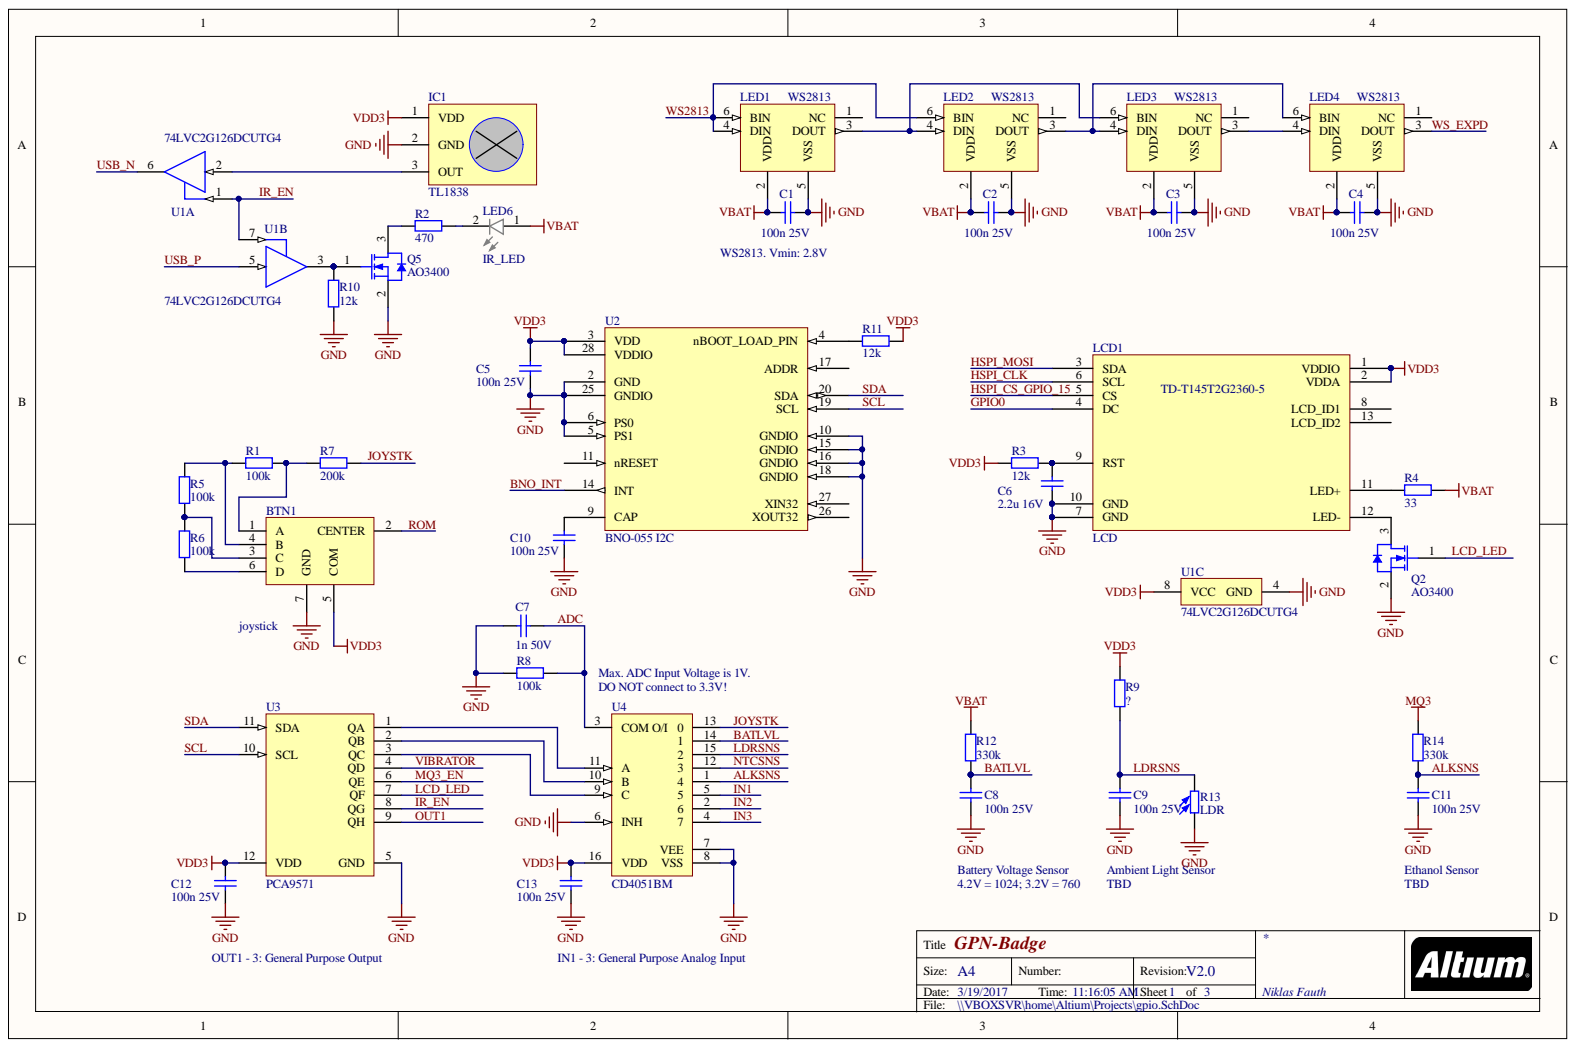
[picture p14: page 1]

Max. ADC Input Voltage is 1V.
DO NOT connect to 3.3V!
COM O/I 3

GPN-Badge Title | * Niklas Fauth

Size: A4 | Number: | Revision: V2.0

Date: 3/19/2017 Time: 11:16:05 AM | | Sheet 1 of 3
File: \\VBOXSVR\home\Altium\Projects\gpio.SchDoc

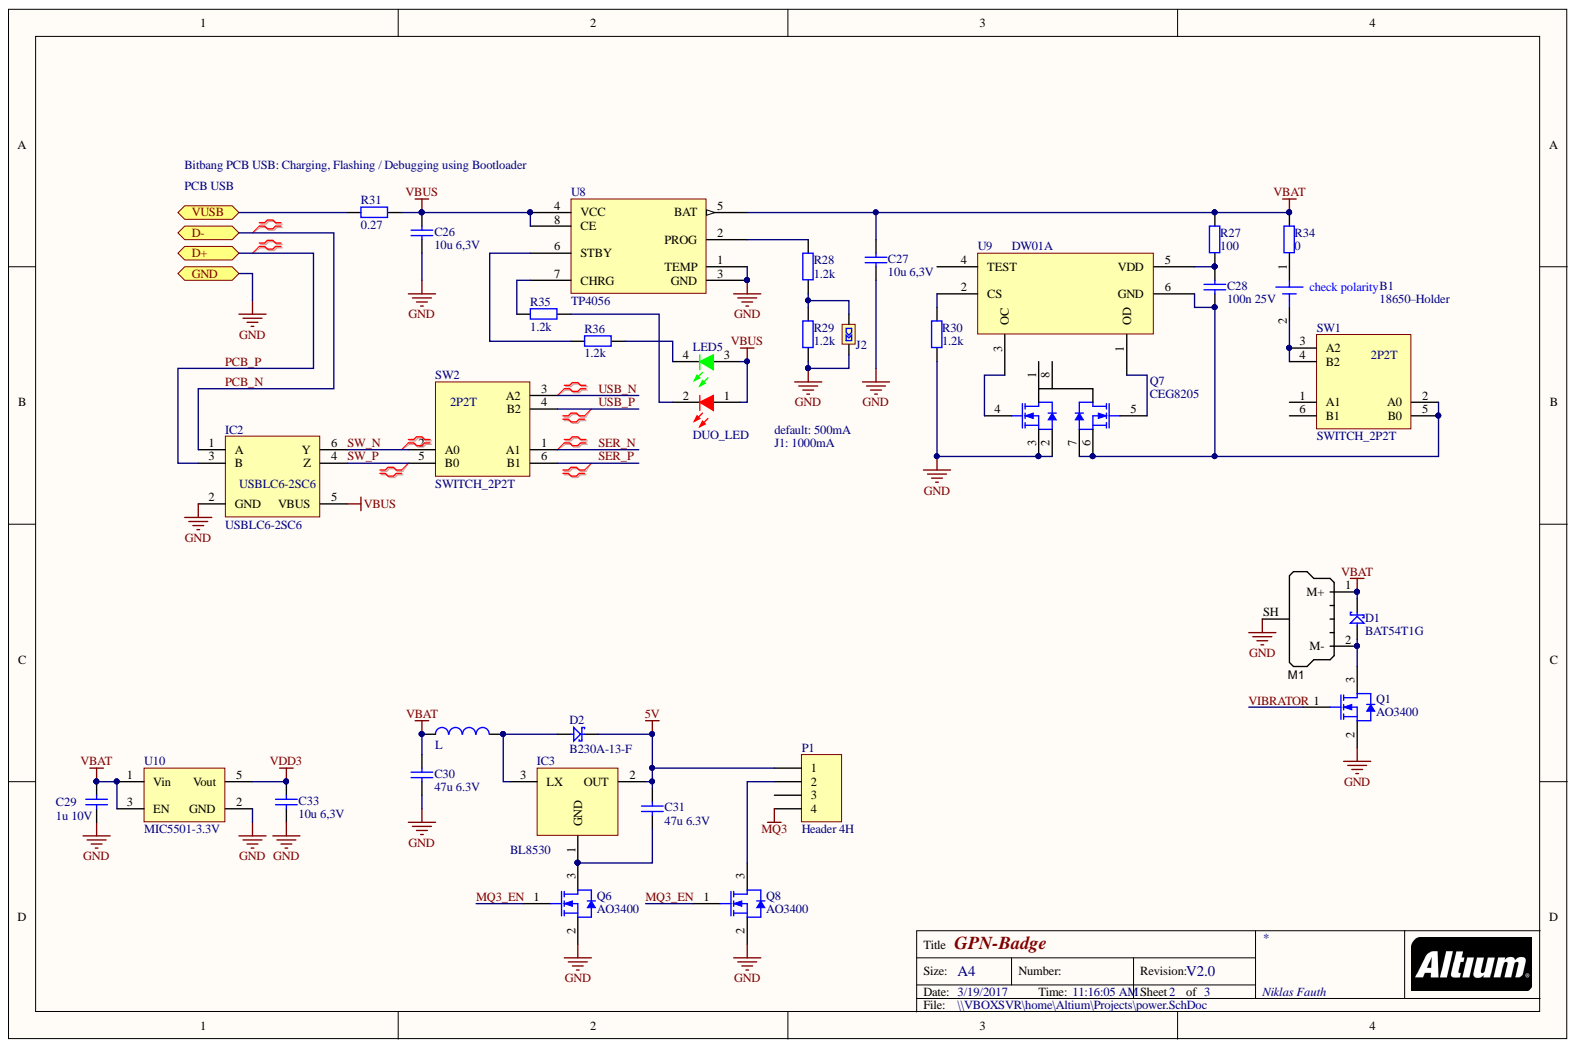
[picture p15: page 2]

Bitbang PCB USB: Charging, Flashing / Debugging using Bootloader
VBAT PCB USB

C26 SW2 | | STBY 6

SWITCH_2P2T SER_N

USBLC6-2SC6 | SW_P

GPN-Badge Title | * Niklas Fauth

Size: A4 | Number: | Revision: V2.0

Date: 3/19/2017 Time: 11:16:05 AM | | Sheet 2 of 3
File: \\VBOXSVR\home\Altium\Projects\power.SchDoc

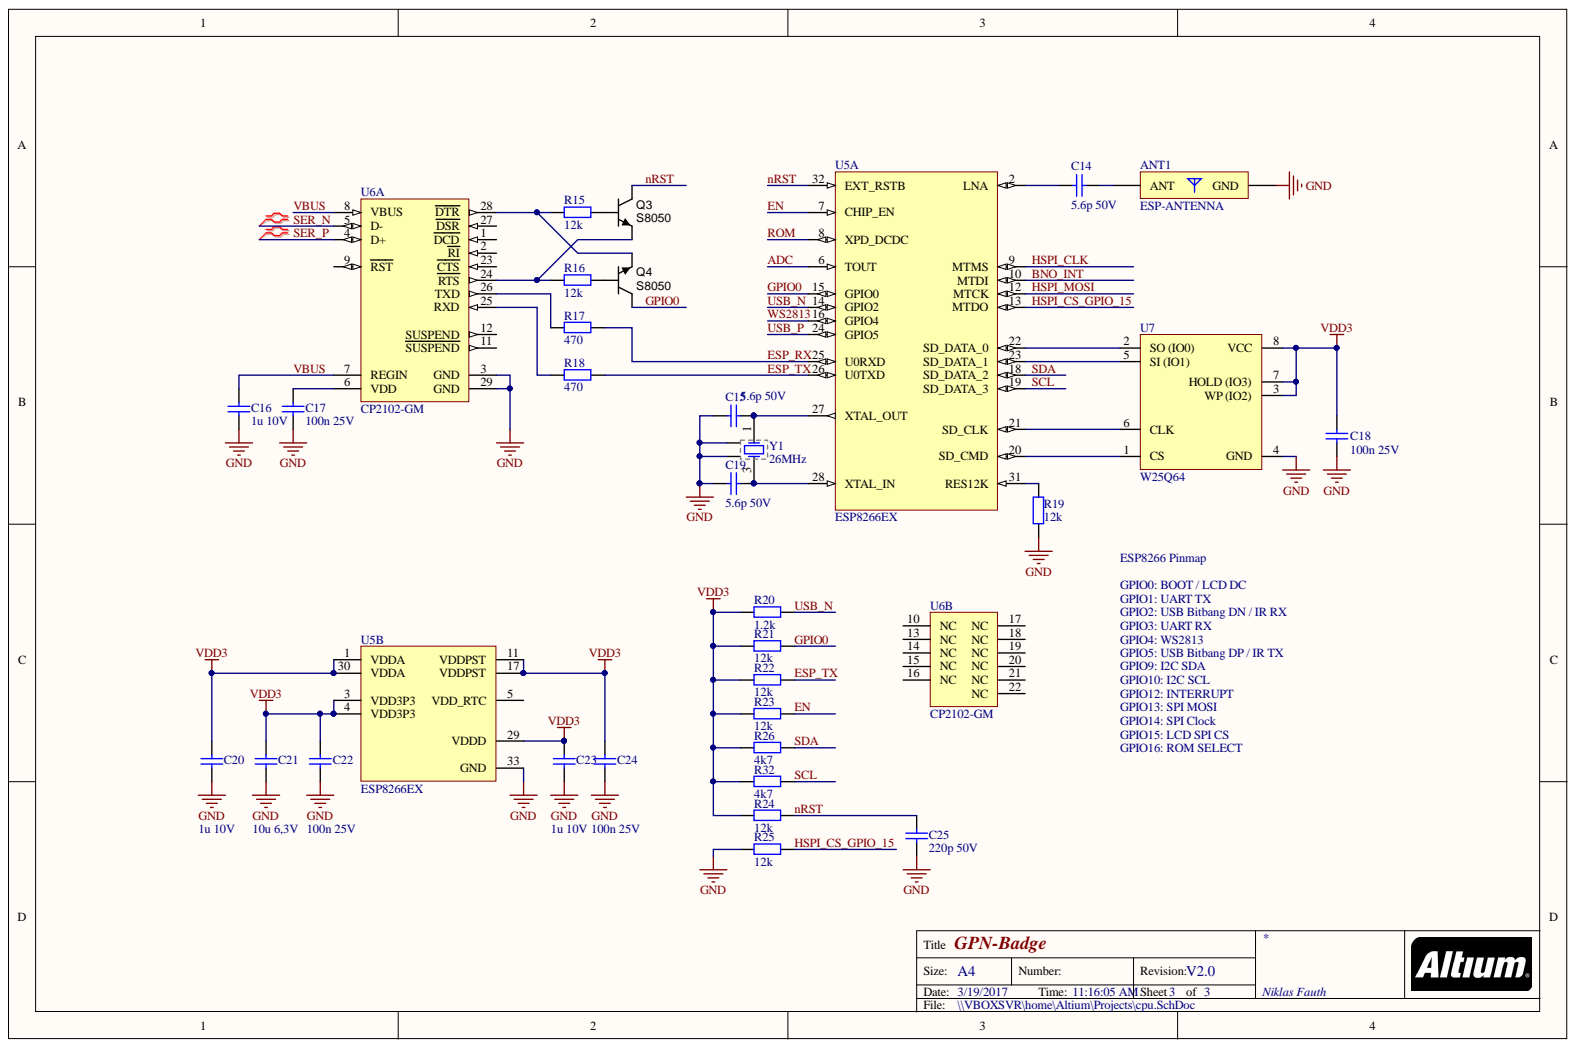
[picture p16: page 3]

GPN-Badge | * Niklas Fauth

A 4 | Numbe r : | R evision: V 2.0

D ate : 3/19/2017 Time : 11:16:05 AM | | She e t 3 of 3
File : \\V B O X S V R\home\Altium\P roje cts\cpu. S chDoc

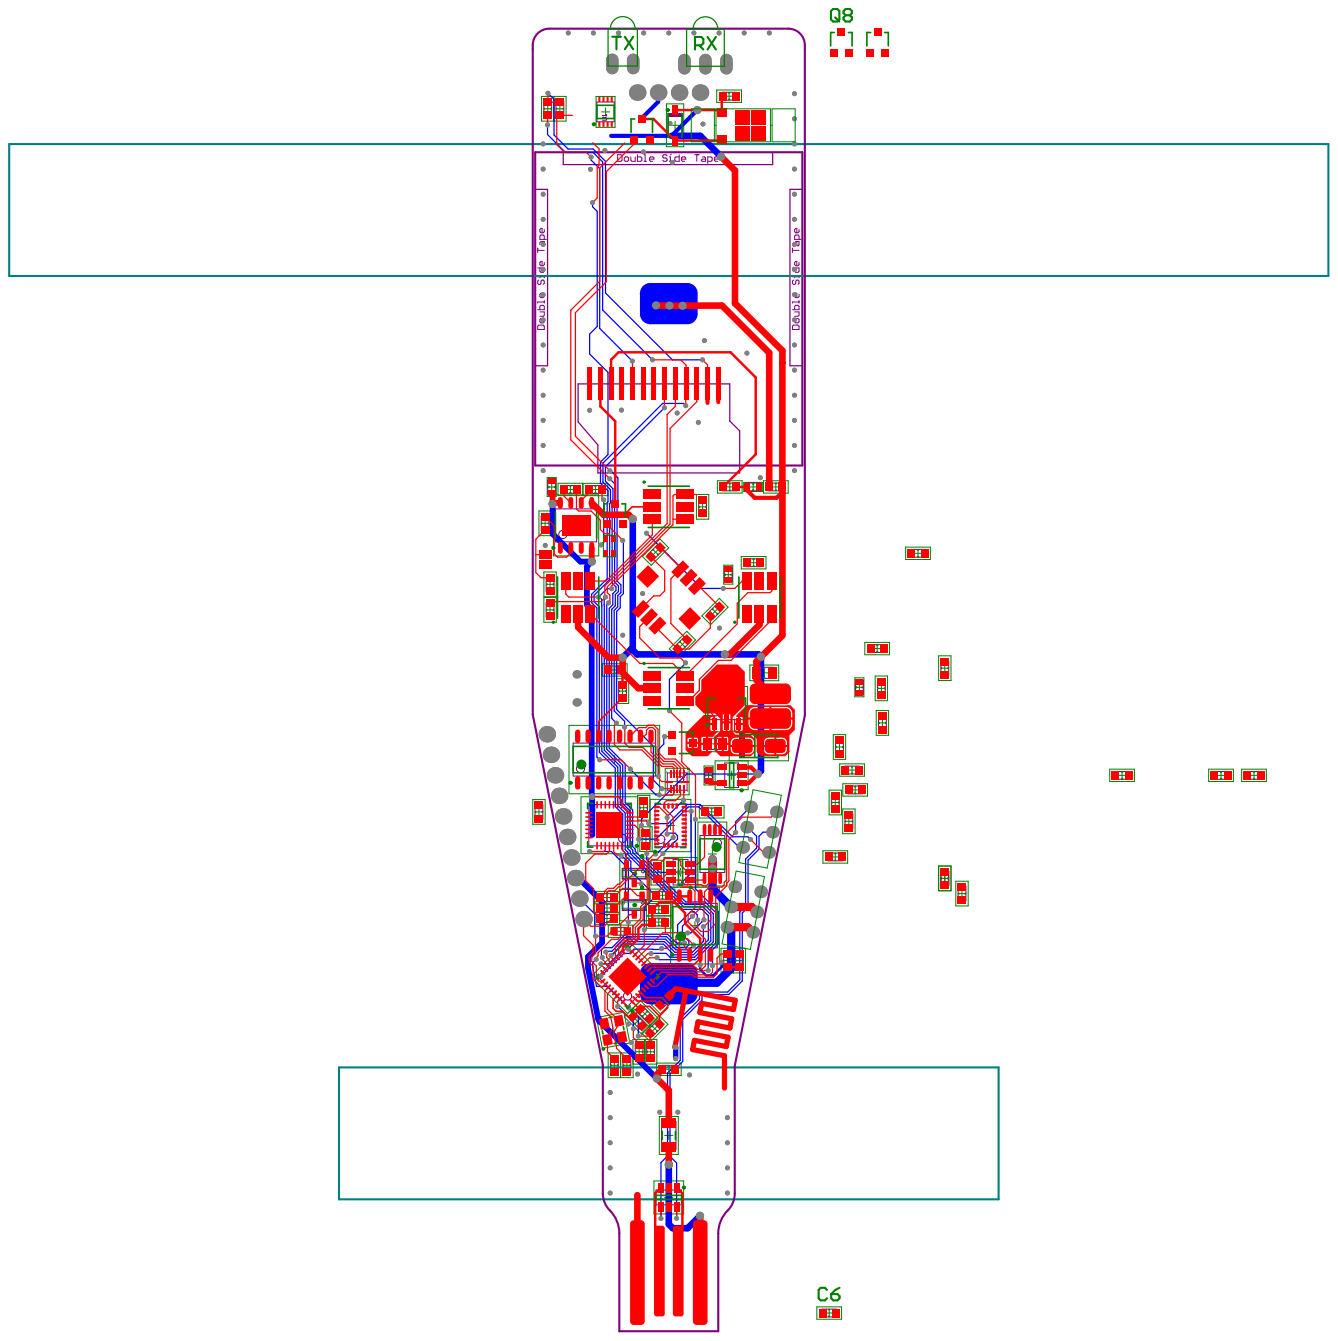
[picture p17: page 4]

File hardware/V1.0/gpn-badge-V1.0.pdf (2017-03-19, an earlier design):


GPIO0: BOOT / LCD DC
GPIO1: UART TX
GPIO2: WS2813
GPIO3: UART RX
GPIO4: USB Bitbang DN
GPIO5: USB Bitbang DP
GPIO9: Shift Register LATCH
GPIO10: LCD Backlight PWM
GPIO12: SPI MISO
GPIO13: SPI MOSI
GPIO14: SPI Clock
GPIO15: LCD SPI CS
GPIO16: MPU6500 CS / WAKE / BOOT SELECT

Title * | * * * * *

Size: A4 | Number: * | Revision: *

Date: 3/9/2017 Time: 2:58:54 AM | | Sheet * of *
File: \\VBOXSVR\home\Altium\Projects\cpu.SchDoc


Max. ADC Input Voltage is 1V.
DO NOT connect to 3.3V!
COM O/I 3

Title * | * * * * *

Size: A4 | Number: * | Revision: *

Date: 3/9/2017 Time: 2:58:54 AM | | Sheet * of *
File: \\VBOXSVR\home\Altium\Projects\gpio.SchDoc


Micro USB: Charging, Flashing / Debugging using USB / UART

STBY 6

Bitbang PCB USB: Charging, Flashing / Debugging using Bootloader

Title * | * * * * *

Size: A4 | Number: * | Revision: *

Date: 3/9/2017 Time: 2:58:54 AM | | Sheet * of *
File: \\VBOXSVR\home\Altium\Projects\power.SchDoc


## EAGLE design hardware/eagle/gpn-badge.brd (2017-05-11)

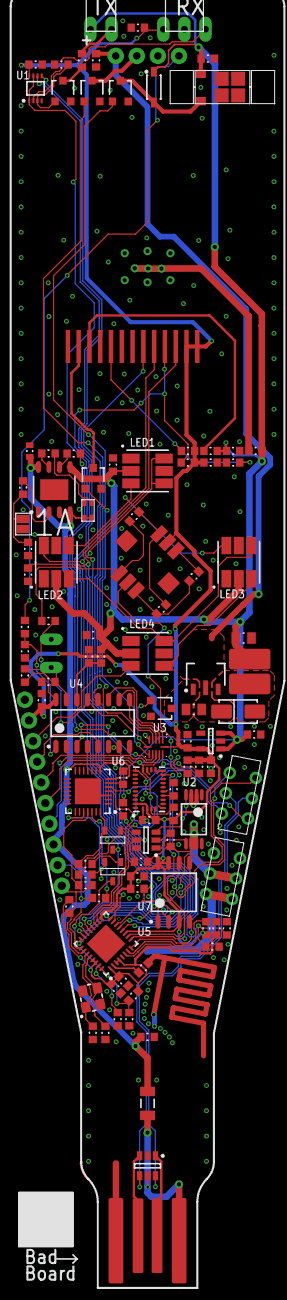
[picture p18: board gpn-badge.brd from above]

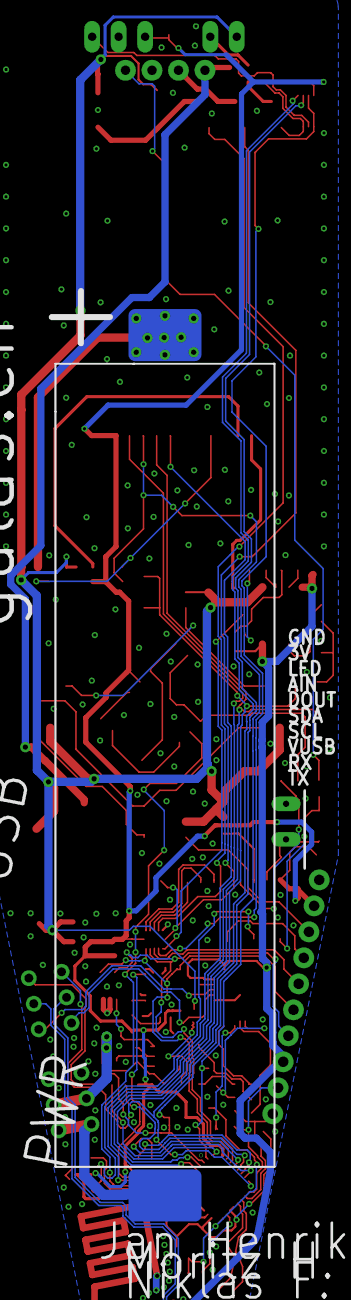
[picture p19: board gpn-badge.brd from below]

Board: 2 copper layers, 139 parts (2 on the bottom side), 50 nets.

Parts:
ANT1: ESP-ANTENNA; ESP8266_ANT_1PRIMARY
B1: 18650-Holder; 18650HOLDER-SMD_1PRIMARY
BTN1: joystick; JOYSTICK_1PRIMARY
C1, C3, C6, C9, C18, C32, C34, C35: 100n_25V; C-0603-M_1PRIMARY
C2, C5, C10, C13, C17, C22, C24: 100n_25V; C-0603-M_3PRIMARY
C7: 220p_50V; C-0603-M_3PRIMARY
C14: 5.6p_50V; C-0603-M_5PRIMARY
C15, C19: 5.6p_50V; C-0603-M_1PRIMARY
C16, C23: 1u_10V; C-0603-M_3PRIMARY
C20: 1u_10V; C-0603-M_4PRIMARY
C21: 10u_6,3V; C-0603-M_2PRIMARY
C25: 220p_50V; C-0603-M_1PRIMARY
C26: 10u_6,3V; C-0603-H_1PRIMARY
C27: 10u_6,3V; C-0603-M_3PRIMARY
C29, C36: 1u_10V; C-0603-M_1PRIMARY
C30, C31: 47u_6.3V; C-0805-M_1PRIMARY
D1: BAT54T1G; SOD123_1PRIMARY
D2: B230A-13-F; DIODE-SMA_1PRIMARY
D3: RB520S30T1G; C-0603-M_3PRIMARY
DUMMY1, DUMMY2, DUMMY3, DUMMY18, DUMMY19, DUMMY20, DUMMY21, DUMMY22, DUMMY23, DUMMY24: P:EX79Y79D391
DUMMY4, DUMMY5, DUMMY6, DUMMY7, DUMMY8, DUMMY9, DUMMY10, DUMMY11, DUMMY12, DUMMY13, DUMMY14, DUMMY15: P:EX0Y0D1931
DUMMY16, DUMMY17: P:EX0Y0D2361
DUMMY25, DUMMY26: P:EX0Y0D1381
DUMMY27, DUMMY28: EF59X39TOP1
DUMMY29, DUMMY30: EF51X354TOP1
DUMMY31, DUMMY32: EF70X406TOP1
IC1: TL1838; TL1838_1PRIMARY
IC2: USBLC6-2SC6; SOT23-6_1PRIMARY
IC3: BL8530; SOT89-150P409X160-3N_1PRIMARY
L1: L; L_1PRIMARY
LCD1: LCD; LCD_1PRIMARY
LED1, LED2, LED3, LED4: WS2813; PLCC6_1PRIMARY
LED5: DUO_LED; LEDDUO_1PRIMARY
LED6: IR_LED; IR_LED_1PRIMARY
M1: VIBRATOR; VIBRATOR_SMD_1PRIMARY
P1: Header_4H; HDR1X4H_WO_SILK_1PRIMARY
Q1, Q2, Q5, Q8: AO3400; AO-SOT23-3_V_1PRIMARY
Q3, Q4: NPN_MMBT3904; SOT23-3_1PRIMARY
Q6: AO3400; AO-SOT23-3_V_2PRIMARY
Q7: CEG8205; SOP64P640X265-8N_1PRIMARY
R1, R6, R8: 100k; R-0603-M_1PRIMARY
R2, R27: 100; R-0603-M_2PRIMARY
R3, R10, R11, R15, R16, R19, R23, R24, R25: 12k; R-0603-M_1PRIMARY
R4: 33; R-0603-M_2PRIMARY
R5: 100k; R-0603-M_4PRIMARY
R7: 200k; R-0603-M_1PRIMARY
R9: 100k; R-0603-M_2PRIMARY
R12, R14: 330k; R-0603-M_1PRIMARY
R13: LDR; LDR-5MM_1PRIMARY
R17: 470; R-0603-M_3PRIMARY
R18, R35, R36: 470; R-0603-M_1PRIMARY
R20, R28, R29: 1.2k; R-0603-M_2PRIMARY
R21: 4k7; R-0603-M_1PRIMARY
R22: 12k; R-0603-M_2PRIMARY
R26, R32: 4k7; R-0603-M_2PRIMARY
R30: 1.2k; R-0603-M_1PRIMARY
R31: 0.27; R-1206-M_1PRIMARY
R33, R37: 1M; R-0603-M_2PRIMARY
R34: 0; R-0603-M_1PRIMARY
SW1, SW2: SWITCH_2P2T; SWITCH_THT_1PRIMARY
U1: 74LVC2G125; DCU0008A_L_1PRIMARY
U2: BNO-055_I2C; BNO-055_1PRIMARY
U3: PCA9571; SON40P210X100-10N_1PRIMARY
U4: CD4051BM; D0016A_M_1PRIMARY
U5: ESP8266EX; QFN32-5X5MM_1PRIMARY
U6: CP2102-GM; SLAB-QFN-28-3125X3125TP_M_1PRIMARY
U7: W25Q64; SOIC127P790X100-8N_1PRIMARY
U8: TP4056; SOIC127P600X20_HS-9N_1PRIMARY
U9: DW01A; SOT23-6_1PRIMARY
U10: MIC5501-3.3V; SOT23-5_1PRIMARY
Y1: 26MHz; 3225_1PRIMARY

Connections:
ADC: C7.1, R8.2, U4.3
ALKSNS: R14.1, R37.2, U4.1
BATLVL: R12.1, R33.2, U4.14
ESP_TX: R18.2, R22.2
GND: ANT1.2, IC1.2
IR_EN: U1.1, U1.7, U3.8
JOYSTK: R7.1, U4.13
LCD_LED: Q2.1, U3.7
LCD_RES: C6.2, LCD1.9, R3.2
MQ3_EN: Q6.1, Q8.1, U3.6
NETANT1_1: ANT1.1, C14.2
NETB1_2: SW1.3, SW1.4
NETC10_2: C10.2, U2.9
NETC15_2: C15.2, Y1.1
NETC19_2: C19.2, Y1.3
NETC31_1: C31.1, IC3.1, Q6.3
NETD1_1: D1.1, M1.2, Q1.3
NETD2_1: D2.1, IC3.3, L1.2
NETD3_1: D3.1, R27.1, U9.5
NETD3_2: D3.2, Q7.6, Q7.7, R30.1, SW1.2, SW1.5, U9.6
NETIC1_3: IC1.3, U1.2
NETJ2_1: R28.1, R29.2
NETLCD1_11: LCD1.11, R4.1
NETLCD1_12: LCD1.12, Q2.3
NETLED5_2: LED5.2, R35.2
NETLED5_4: LED5.4, R36.2
NETLED6_2: LED6.2, R2.1
NETQ3_1: Q3.2, R15.2
NETQ4_1: Q4.2, R16.2
NETQ5_1: Q5.1, R10.2, U1.3
NETQ5_3: Q5.3, R2.2
NETQ7_4: Q7.4, U9.3
NETQ7_5: Q7.5, U9.1
NETR11_1: R11.1, U2.4
NETR28_2: R28.2, U8.2
NETR30_2: R30.2, U9.2
NETR35_1: R35.1, U8.7
NETR36_1: R36.1, U8.6
NETU3_1: U3.1, U4.11
NETU3_2: U3.2, U4.10
NETU3_3: U3.3, U4.9
NRST: C25.2, Q3.4, R24.2
SW_N: IC2.6, SW2.2
SW_P: IC2.4, SW2.5
USB_N: R20.1, SW2.3, U1.6
USB_P: SW2.4, U1.5
VBAT: D1.2, LED6.1, M1.1
VBUS: LED5.1, LED5.3, U8.4, U8.8
VIBRATOR: Q1.1, U3.4
VUSB: IC2.5, R31.1

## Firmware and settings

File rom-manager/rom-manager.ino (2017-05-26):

#include <Adafruit_GFX.h>
#include <TFT_ILI9163C.h>
#include <Adafruit_NeoPixel.h>
#include <ESP8266WebServer.h>
#include <Wire.h>


#include "rboot.h"
#include "rboot-api.h"

#include <ArduinoJson.h>

#include "url-encode.h"
#include <FS.h>

#include <ESP8266HTTPClient.h>
#include <ESP8266httpUpdate.h>

ESP8266WebServer server(80);
//holds the current upload
File fsUploadFile;


#include <ESP8266WiFi.h>
#include <ESP8266HTTPClient.h>
#include <Fonts/FreeSans9pt7b.h>
#include <gfxfont.h>

#define GPIO_LCD_DC 0
#define GPIO_TX     1
#define GPIO_WS2813 4
#define GPIO_RX     3
#define GPIO_DN     2
#define GPIO_DP     5

#define GPIO_BOOT   16
#define GPIO_MOSI   13
#define GPIO_CLK    14
#define GPIO_LCD_CS 15
#define GPIO_BNO    12

#define MUX_JOY 0
#define MUX_BAT 1
#define MUX_LDR 2
#define MUX_ALK 4
#define MUX_IN1 5

#define VIBRATOR 3
#define MQ3_EN   4
#define LCD_LED  5
#define IR_EN    6
#define OUT1     7

#define UP      807
#define DOWN    648
#define RIGHT   540
#define LEFT    1024
#define OFFSET  50

#define I2C_PCA 0x25

#define NUM_LEDS    4

// Color definitions
#define BLACK   0x0000
#define BLUE    0x001F
#define RED     0xF800
#define GREEN   0x07E0
#define CYAN    0x07FF
#define MAGENTA 0xF81F
#define YELLOW  0xFFE0
#define WHITE   0xFFFF

TFT_ILI9163C tft = TFT_ILI9163C(GPIO_LCD_CS, GPIO_LCD_DC);
Adafruit_NeoPixel pixels = Adafruit_NeoPixel(NUM_LEDS, GPIO_WS2813, NEO_GRB + NEO_KHZ800);

//global variables
byte shiftConfig = 0; //stores the PCA config

void setup() {
  //ESP.eraseConfig();
  WiFi.persistent(false);

  initBadge();
reset:
  tft.clear();
  tft.writeFramebuffer();

  Serial.println("Purr!"); //useful debug message

  if (!SPIFFS.begin()) { //initialize the spiffs
    // TODO
    Serial.println("Error init SPIFFS!");
  }

  Serial.println(ESP.getFlashChipSize());


  setGPIO(LCD_LED, HIGH);

  tft.setFont(&FreeSans9pt7b);
  tft.setTextColor(YELLOW);
  tft.setCursor(2, 15);
  tft.print("ROM Manager");
  tft.drawLine(2, 18, 126, 18, WHITE);
  tft.drawLine(2, 112, 126, 112, WHITE);

  tft.setFont();
  tft.setTextSize(1);

  int adc;
  int bat;
  int romNumber = 1, lastRomNumber = 0;
  bool stillPressed = true;
  setAnalogMUX(MUX_JOY);
  String romNames[11] ;
  for (int i = 1; i < 10; i++) {
    File f = SPIFFS.open("/rom" + String(i), "r");
    if (f) {
      romNames[i] = f.readStringUntil('\n');
      Serial.println(romNames[i]);
    }
  }
  romNames[0] = "ROM Manager";

  while ((digitalRead(16) == LOW) || stillPressed) {
    delay(1);
    adc = analogRead(A0);

    if (digitalRead(16) == LOW)
      stillPressed = false;

    if (adc < UP + OFFSET && adc > UP - OFFSET) {
      romNumber--;
    }

    else if (adc < DOWN + OFFSET && adc > DOWN - OFFSET) {
      romNumber++;
    }

    if (romNumber > 11)
      romNumber = 1;

    if (romNumber < 1)
      romNumber = 11;

    if ( lastRomNumber != romNumber) {
      for (int i = 1; i < 10; i++) {

        if (i == romNumber) {
          //tft.fillRect(2, 12+10*i, 125, 9, WHITE);
          tft.setTextColor(BLACK, WHITE);
        }

        else {
          //tft.fillRect(2, 12+10*i, 125, 9, BLACK);
          tft.setTextColor(WHITE, BLACK);
        }

        tft.setCursor(3, 13 + 10 * i);
        String entry = "Slot " + String(i) + ": " + romNames[i];
        int whitespace = 20 - entry.length();
        for (int i = 0; i < whitespace; i++) {
          entry += " ";
        }
        tft.print(entry);
      }

      if (romNumber == 10) {
        //tft.fillRect(2, 116, 60, 10, WHITE);
        tft.setTextColor(BLACK , WHITE);
        tft.setCursor(3, 117);
        tft.print("ROM Store");

        //tft.fillRect(66, 116, 60, 10, BLACK);
        tft.setTextColor(YELLOW, BLACK);
        tft.setCursor(72, 117);
        tft.print("Utilities");
      }

      else if (romNumber == 11) {
        //tft.fillRect(66, 116, 60, 10, WHITE);
        tft.setTextColor(BLACK, WHITE);
        tft.setCursor(72, 117);
        tft.print("Utilities");

        //tft.fillRect(2, 116, 60, 10, BLACK);
        tft.setTextColor(YELLOW, BLACK);
        tft.setCursor(3, 117);
        tft.print("ROM Store");
      }

      else {
        //tft.fillRect(2, 116, 125, 10, BLACK);
        tft.setTextColor(YELLOW, BLACK);
        tft.setCursor(3, 117);
        tft.print("ROM Store");
        tft.setCursor(72, 117);
        tft.print("Utilities");
      }
      lastRomNumber = romNumber;
      tft.writeFramebuffer();
    }

  }

  Serial.print("Selected: ");
  Serial.println(romNumber);

  tft.clear();
  tft.writeFramebuffer();

  bool ledVal = 0;

  if (romNumber == 11) {
    tft.setFont(&FreeSans9pt7b);
    tft.setTextColor(YELLOW);
    tft.setCursor(2, 15);
    tft.print("Utilities");
    tft.drawLine(2, 18, 126, 18, WHITE);
    tft.drawLine(2, 112, 126, 112, WHITE);

    tft.setFont();
    tft.setTextSize(1);

    romNumber = 4;
    stillPressed = true;
    setAnalogMUX(MUX_JOY);
    String menu[] = {"SPIFFS Uploader", "Vibrator", "Torch", "About", "Back"};
    while ((digitalRead(16) == LOW) || stillPressed) {
      delay(10);
      adc = analogRead(A0);

      if (digitalRead(16) == LOW)
        stillPressed = false;

      if (adc < UP + OFFSET && adc > UP - OFFSET) {
        romNumber--;
        delay(15);
      }

      else if (adc < DOWN + OFFSET && adc > DOWN - OFFSET) {
        romNumber++;
        delay(15);
      }

      if (romNumber > 4)
        romNumber = 0;

      if (romNumber < 0)
        romNumber = 4;

      for (int i = 0; i < 5; i++) {

        if (i == romNumber) {
          tft.setTextColor(BLACK, WHITE);
        }

        else {
          tft.setTextColor(YELLOW, BLACK);
        }

        tft.setCursor(3, 23 + 10 * i);
        String entry = " " + menu[i];
        int whitespace = 19 - menu[i].length();
        for (int i = 0; i < whitespace; i++) {
          entry += " ";
        }
        tft.print(entry);

      }
      tft.writeFramebuffer();

      if (romNumber == 1) {
        if (digitalRead(16) == HIGH) {
          setGPIO(VIBRATOR, HIGH);
        }
        while (digitalRead(16) == HIGH) {
          delay(10);
        }
        setGPIO(VIBRATOR, LOW);
        stillPressed = true;
      }

      if (romNumber == 2) {
        if (digitalRead(16) == HIGH) {
          ledVal = !ledVal;
        }
        while (digitalRead(16) == HIGH) {
          delay(10);
        }
        stillPressed = true;
      }

      pixels.setPixelColor(1, pixels.Color(ledVal * 255, ledVal * 255, ledVal * 255));
      pixels.setPixelColor(2, pixels.Color(ledVal * 255, ledVal * 255, ledVal * 255));
      pixels.setPixelColor(3, pixels.Color(ledVal * 255, ledVal * 255, ledVal * 255));
      pixels.setPixelColor(0, pixels.Color(ledVal * 255, ledVal * 255, ledVal * 255));
      pixels.show();
    }

    if (romNumber == 0) {
      tft.clear();
      tft.writeFramebuffer();
      tft.setFont(&FreeSans9pt7b);
      tft.setTextColor(YELLOW);
      tft.setCursor(2, 15);
      tft.print("File Editor");
      tft.drawLine(2, 18, 126, 18, WHITE);

      initServer();

      while (digitalRead(16) == LOW) {
        server.handleClient();
      }

      ESP.eraseConfig();
      ESP.reset();
    }

    if (romNumber == 3) {
      tft.clear();
      tft.writeFramebuffer();
      tft.setFont(&FreeSans9pt7b);
      tft.setTextColor(YELLOW);
      tft.setCursor(0, 15);
      tft.println("GPN17 Badge\nROM Manager");

      tft.setFont();
      tft.setTextColor(WHITE);
      tft.println("Developed by \nNiklas Fauth\nTwitter: @FauthNiklas\n\n*otter*");

      while (digitalRead(16) == LOW) {
        delay(100);
      }

      goto reset;
    }

    if (romNumber == 4) {
      ledVal = 0;
      pixels.setPixelColor(1, pixels.Color(ledVal * 255, ledVal * 255, ledVal * 255));
      pixels.setPixelColor(2, pixels.Color(ledVal * 255, ledVal * 255, ledVal * 255));
      pixels.setPixelColor(3, pixels.Color(ledVal * 255, ledVal * 255, ledVal * 255));
      pixels.setPixelColor(0, pixels.Color(ledVal * 255, ledVal * 255, ledVal * 255));
      pixels.show();
      tft.clear();
      goto reset;
    }
  }


  if (romNumber == 10) {
    int ledVal = 0;
    bool up = true;
    Serial.println("Loading config.");

    tft.setFont();
    tft.setTextSize(1);
    tft.setTextColor(RED);
    tft.setCursor(0, 2);
    tft.println("Reading wifi.conf...");
    tft.writeFramebuffer();

    tft.setTextColor(WHITE);

    File wifiConf = SPIFFS.open("/wifi.conf", "r");

    if (!wifiConf) {
      tft.println("File not found!");
      tft.writeFramebuffer();
      delay(5000);
      goto reset;
    }
    String configString;
    while (wifiConf.available()) {
      configString += char(wifiConf.read());
    }
    wifiConf.close();
    UrlDecode confParse(configString.c_str());
    Serial.println(configString);
    configString = String();
    char* ssid = confParse.getKey("ssid");
    char* pw = confParse.getKey("pw");
    Serial.printf("Connecting to wifi '%s' with password '%s'...\n", ssid, pw);

    tft.println("Connecting to SSID:");
    tft.println(ssid);
    tft.writeFramebuffer();

    WiFi.disconnect();
    WiFi.mode(WIFI_OFF);
    delay(400);
    WiFi.mode(WIFI_AP);
    delay(400);
    WiFi.disconnect();
    WiFi.mode(WIFI_OFF);
    delay(400);
    WiFi.mode(WIFI_STA);
    WiFi.begin(ssid, pw);

    unsigned long startTime = millis();
    //delete[] pw;
    while (WiFi.status() != WL_CONNECTED) {
      pixels.setPixelColor(1, pixels.Color(0, 0, ledVal));
      pixels.setPixelColor(2, pixels.Color(0, 0, ledVal));
      pixels.setPixelColor(3, pixels.Color(0, 0, ledVal));
      pixels.setPixelColor(0, pixels.Color(0, 0, ledVal));
      pixels.show();
      if (ledVal == 100) {
        up = false;
      }
      if (ledVal == 0) {
        up = true;
      }
      if (up) {
        //ui->root->setSub("Connecting...");
        //ui->draw();
        ledVal++;
      } else {

        ledVal--;
      }
      if (millis() - startTime > 30 * 1000) {

        pixels.setPixelColor(1, pixels.Color(50, 0, 0));
        pixels.setPixelColor(2, pixels.Color(50, 0, 0));
        pixels.setPixelColor(3, pixels.Color(50, 0, 0));
        pixels.setPixelColor(0, pixels.Color(50, 0, 0));
        pixels.show();
        tft.setTextColor(RED);
        tft.println("");
        tft.println("WiFi connect failed!");
        delay(2000);

        ESP.reset();
      }
      delay(10);
    }

    pixels.setPixelColor(1, pixels.Color(0, 0, 0));
    pixels.setPixelColor(2, pixels.Color(0, 0, 0));
    pixels.setPixelColor(3, pixels.Color(0, 0, 0));
    pixels.setPixelColor(0, pixels.Color(0, 0, 0));
    pixels.show();
    
    //delete[] ssid;
    tft.setTextColor(GREEN);
    tft.println("");
    tft.println("WiFi connected!");
    tft.setTextColor(WHITE);
    tft.println(WiFi.localIP().toString());
    tft.writeFramebuffer();
    Serial.println("WiFi connected");
    Serial.println("");
    Serial.println(WiFi.localIP());

    pixels.show();

    delay(2000);

    pixels.setPixelColor(1, pixels.Color(0, 0, 0));
    pixels.setPixelColor(2, pixels.Color(0, 0, 0));
    pixels.setPixelColor(3, pixels.Color(0, 0, 0));
    pixels.setPixelColor(0, pixels.Color(0, 0, 0));
    pixels.show();

    tft.clear();
    tft.writeFramebuffer();

    tft.setFont();
    tft.setTextSize(1);
    tft.setTextColor(RED);
    tft.setCursor(0, 2);
    tft.println("Reading store.conf...");
    tft.writeFramebuffer();

    File storeConf = SPIFFS.open("/store.conf", "r");
    if (!storeConf) {
      tft.println("File not found!");
      tft.writeFramebuffer();
      delay(5000);
      goto reset;
    }

    tft.setTextColor(WHITE);
    configString;
    while (storeConf.available()) {
      configString += char(storeConf.read());
    }
    storeConf.close();
    UrlDecode storeParse(configString.c_str());
    Serial.println(configString);
    configString = String();
    char* store = storeParse.getKey("url");
    char* httpPort = storeParse.getKey("port");
    char* fingerprint = storeParse.getKey("fingerprint");
    Serial.printf("Store address is '%s'\n", store);

    tft.println("Found ROM Store:");
    tft.println(store);
    tft.println("Port:");
    tft.println(atoi(httpPort));
    tft.writeFramebuffer();

    String updateURL = "";
{
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
void loop() {
}

void HSVtoRGB(int hue, int sat, int val, int colors[3])
{
  // hue: 0-359, sat: 0-255, val (lightness): 0-255
  int r, g, b, base;
  if (sat == 0)
  { // Achromatic color (gray).
    colors[0] = val;
    colors[1] = val;
    colors[2] = val;
  }
  else
  {
    base = ((255 - sat) * val) >> 8;
    switch (hue / 60)
    {
      case 0:
        r = val;
        g = (((val - base) * hue) / 60) + base;
        b = base;
        break;
      case 1:
        r = (((val - base) * (60 - (hue % 60))) / 60) + base;
        g = val;
        b = base;
        break;
      case 2:
        r = base;
        g = val;
        b = (((val - base) * (hue % 60)) / 60) + base;
        break;
      case 3:
        r = base;
        g = (((val - base) * (60 - (hue % 60))) / 60) + base;
        b = val;
        break;
      case 4:
        r = (((val - base) * (hue % 60)) / 60) + base;
        g = base;
        b = val;
        break;
      case 5:
        r = val;
        g = base;
        b = (((val - base) * (60 - (hue % 60))) / 60) + base;
        break;
    }
    colors[0] = r;
    colors[1] = g;
    colors[2] = b;
  }
}





void initServer() {

  tft.setFont();
  tft.setTextSize(1);
  tft.setCursor(0, 23);
  tft.setTextColor(WHITE);
  tft.println("Creating WiFi AP...");

  SPIFFS.begin();
  {
    Dir dir = SPIFFS.openDir("/");
    while (dir.next()) {
      String fileName = dir.fileName();
      size_t fileSize = dir.fileSize();
      Serial.printf("FS File: %s, size: %s\n", fileName.c_str(), formatBytes(fileSize).c_str());
    }
    Serial.printf("\n");
  }

  Serial.printf("Free heap at init: %d\n", ESP.getFreeHeap());
  
  WiFi.mode(WIFI_AP);
  WiFi.softAPConfig(IPAddress (10, 0, 0, 1), IPAddress(10, 0, 0, 1), IPAddress(255, 255, 255, 0));
  char pw[20];
  char ssid[20];
  sprintf(pw, "%d", random(10000000, 100000000)); // TODO richtig machen
  sprintf(ssid, "ESP%d", ESP.getChipId());
  //sprintf(pw, "%s", "hallohallo");
  
  Serial.println(WiFi.softAP(ssid, pw));

  tft.setTextColor(GREEN);
  tft.println("Done!");
  tft.setTextColor(WHITE);
  tft.println(" ");
  tft.println("SSID: ");
  tft.println(ssid);
  tft.setCursor(0, 67);
  tft.println("Password: ");

  //FullScreenBMPStatus* webStatus = new FullScreenBMPStatus();
  //connectWizard(ssid, pw, webStatus);
  bool dispPw = false;

  int last_b = millis();

  bool b_state = false;

  tft.setCursor(0, 75);
  tft.setTextColor(WHITE, BLACK);
  tft.println("Press Center.");
  tft.writeFramebuffer();
  bool toogleSwitch = false;
  bool up = true;
  int ledVal = 0;
  while (true) {
    pixels.setPixelColor(1, pixels.Color(0, ledVal, 0));
    pixels.setPixelColor(2, pixels.Color(0, ledVal, 0));
    pixels.setPixelColor(3, pixels.Color(0, ledVal, 0));
    pixels.setPixelColor(0, pixels.Color(0, ledVal, 0));
    pixels.show();
    if (ledVal == 100) {
      up = false;
    }
    if (ledVal == 0) {
      up = true;
    }
    if (up) {
      //ui->root->setSub("Connecting...");
      //ui->draw();
      ledVal++;
    } else {

      ledVal--;
    }

    if ((digitalRead(16) == HIGH) && !toogleSwitch) {
      toogleSwitch = true;
      dispPw = !dispPw;
      if (dispPw) {
        tft.setCursor(0, 75);
        tft.setTextColor(WHITE, BLACK);
        tft.print(pw);
        tft.println("          ");
        tft.writeFramebuffer();
      } else {
        tft.setCursor(0, 75);
        tft.setTextColor(WHITE, BLACK);
        tft.println("Press Center.");
        tft.writeFramebuffer();
      }
    }
    if (digitalRead(16) == LOW) {
      toogleSwitch = false;
    }

    if (WiFi.softAPgetStationNum() > 0) {
      tft.setTextColor(WHITE, BLACK);;
      tft.setCursor(0, 90);
      tft.println("Please visit:");
      tft.println("10.0.0.1");
      tft.setCursor(0, 118);
      tft.println("Press Center to abort.");
      tft.writeFramebuffer();
      break;
    }
    delay(10);
  }
  pixels.setPixelColor(0, pixels.Color(0, 0, 0));
  pixels.setPixelColor(1, pixels.Color(0, 0, 0));
  pixels.setPixelColor(2, pixels.Color(0, 0, 0));
  pixels.setPixelColor(3, pixels.Color(0, 0, 0));
  pixels.show();


  //SERVER INIT
  //list directory
  server.on("/list", HTTP_GET, handleFileList);
  //load editor
  server.on("/edit", HTTP_GET, []() {
    if (!handleFileRead("/mng/edit.htm")) server.send(404, "text/plain", "FileNotFound");
  });
  //create file
  server.on("/edit", HTTP_PUT, handleFileCreate);
  //delete file
  server.on("/edit", HTTP_DELETE, handleFileDelete);
  //first callback is called after the request has ended with all parsed arguments
  //second callback handles file uploads at that location
  server.on("/edit", HTTP_POST, []() {
    server.send(200, "text/plain", "");
  }, handleFileUpload);

  //called when the url is not defined here
  //use it to load content from SPIFFS
  server.onNotFound([]() {
    if (!handleFileRead(server.uri()))
      server.send(404, "text/plain", "FileNotFound");
  });

  //get heap status, analog input value and all GPIO statuses in one json call
  server.on("/all", HTTP_GET, []() {
    String json = "{";
    json += "\"heap\":" + String(ESP.getFreeHeap());
    json += ", \"analog\":" + String(analogRead(A0));
    json += ", \"gpio\":" + String((uint32_t)(((GPI | GPO) & 0xFFFF) | ((GP16I & 0x01) << 16)));
    json += "}";
    server.send(200, "text/json", json);
    json = String();
  });
  server.begin();
  Serial.println("HTTP server started");
}

//format bytes
String formatBytes(size_t bytes) {
  if (bytes < 1024) {
    return String(bytes) + "B";
  } else if (bytes < (1024 * 1024)) {
    return String(bytes / 1024.0) + "KB";
  } else if (bytes < (1024 * 1024 * 1024)) {
    return String(bytes / 1024.0 / 1024.0) + "MB";
  } else {
    return String(bytes / 1024.0 / 1024.0 / 1024.0) + "GB";
  }
}

String getContentType(String filename) {
  if (server.hasArg("download")) return "application/octet-stream";
  else if (filename.endsWith(".htm")) return "text/html";
  else if (filename.endsWith(".html")) return "text/html";
  else if (filename.endsWith(".css")) return "text/css";
  else if (filename.endsWith(".js")) return "application/javascript";
  else if (filename.endsWith(".png")) return "image/png";
  else if (filename.endsWith(".gif")) return "image/gif";
  else if (filename.endsWith(".jpg")) return "image/jpeg";
  else if (filename.endsWith(".ico")) return "image/x-icon";
  else if (filename.endsWith(".xml")) return "text/xml";
  else if (filename.endsWith(".pdf")) return "application/x-pdf";
  else if (filename.endsWith(".zip")) return "application/x-zip";
  else if (filename.endsWith(".gz")) return "application/x-gzip";
  return "text/plain";
}

bool handleFileRead(String path) {
  Serial.println("handleFileRead: " + path);
  if (path.endsWith("/")) path += "mng/index.htm";
  String contentType = getContentType(path);
  String pathWithGz = path + ".gz";
  if (SPIFFS.exists(pathWithGz) || SPIFFS.exists(path)) {
    if (SPIFFS.exists(pathWithGz))
      path += ".gz";
    File file = SPIFFS.open(path, "r");
    size_t sent = server.streamFile(file, contentType);
    file.close();
    return true;
  }
  return false;
}

void handleFileUpload() {
  if (server.uri() != "/edit") return;
  HTTPUpload& upload = server.upload();
  if (upload.status == UPLOAD_FILE_START) {
    String filename = upload.filename;
    if (!filename.startsWith("/")) filename = "/" + filename;
    Serial.print("handleFileUpload Name: "); Serial.println(filename);
    fsUploadFile = SPIFFS.open(filename, "w");
    filename = String();
  } else if (upload.status == UPLOAD_FILE_WRITE) {
    //Serial.print("handleFileUpload Data: "); Serial.println(upload.currentSize);
    if (fsUploadFile)
      fsUploadFile.write(upload.buf, upload.currentSize);
  } else if (upload.status == UPLOAD_FILE_END) {
    if (fsUploadFile)
      fsUploadFile.close();
    Serial.print("handleFileUpload Size: "); Serial.println(upload.totalSize);
  }
}

void handleFileDelete() {
  if (server.args() == 0) return server.send(500, "text/plain", "BAD ARGS");
  String path = server.arg(0);
  Serial.println("handleFileDelete: " + path);
  if (path == "/")
    return server.send(500, "text/plain", "BAD PATH");
  if (!SPIFFS.exists(path))
    return server.send(404, "text/plain", "FileNotFound");
  SPIFFS.remove(path);
  server.send(200, "text/plain", "");
  path = String();
}
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

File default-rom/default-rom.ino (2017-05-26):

// vim: noai:ts=2:sw=2

//#define DEBUG

#include <GPNBadge.hpp>

#define WEB_SERVER_BUFFER_SIZE 40
#define WEB_SERVER_CLIENT_TIMEOUT 100

#ifdef DEBUG
#define BADGE_PULL_INTERVAL 60000
#else
#define BADGE_PULL_INTERVAL 5*60*1000
#endif

#include <BadgeUI.h>
#include <UIThemes.h>
#include "url-encode.h"
#include <FS.h>
#include "notification_db.h"
#include "WebServer.h"
#include <rboot-api.h>

#include "rboot.h"
#include "rboot-api.h"

// Color definitions
#define BLACK   0x0000
#define BLUE    0x001F
#define RED     0xF800
#define GREEN   0x07E0
#define CYAN    0x07FF
#define MAGENTA 0xF81F
#define YELLOW  0xFFE0
#define WHITE   0xFFFF

#define DEFAULT_THEME "Light"
#define CONFIG_PREFIX "/deflt/conf/"

Badge badge;
WindowSystem* ui = new WindowSystem(&tft);
char writeBuf[WEB_SERVER_BUFFER_SIZE];
Menu * mainMenu = new Menu();
StatusOverlay * status = new StatusOverlay(BAT_CRITICAL, BAT_FULL);
bool autoTheme = false;
bool isDark = false;
unsigned char wifiLight = 255;
int wifi_hue = 0;
int wifi_hue_target = 0;

//Sharing
String shareString;
bool receiveShare = false;

bool ennotif = true;

String getConfig(String key, String def) {
  if(!SPIFFS.exists(CONFIG_PREFIX+key)){
    setConfig(key, def);
    return def;
  }
  File f = SPIFFS.open(CONFIG_PREFIX+key, "r");
  String ret = "";
  while(f.available()) {
    ret += char(f.read());
  }
  f.close();
  if(ret == "" && ret != def) {
    setConfig(key, def);
    return def;
  }
  return ret;
}

void setConfig(String key, String value) {
  File f = SPIFFS.open(CONFIG_PREFIX+key, "w");
  Serial.printf("Conf save: %s value=%s\n", key.c_str(), value.c_str());
  f.print(value);
  f.flush();
  f.close();
} 

void setup() {
  badge.init();

  if (!SPIFFS.begin()) { //initialize the spiffs
    // TODO
    Serial.print("Error init SPIFFS!");
  }

  badge.setBacklight(true);
  ui->root->setBmp("/deflt/load.bmp", 40, 12);
  ui->root->setSub("");
  ui->setOverlay(status);
  ui->draw();

  Serial.print("Battery Voltage:  ");
  Serial.println(badge.getBatVoltage());
  Serial.print("Light LDR Level:  ");
  Serial.println(badge.getLDRLvl());



  //setGPIO(VIBRATOR, HIGH);
  //delay(500);
  //setGPIO(VIBRATOR, LOW);

  badge.setGPIO(IR_EN, LOW);

  badge.setAnalogMUX(MUX_JOY);

  deleteTimestampFiles();

  rboot_config rboot_config = rboot_get_config();
  Serial.print("I am in Slot ");
  Serial.println(rboot_config.current_rom);

  SPIFFS.begin();
  File f = SPIFFS.open("/rom" + String(rboot_config.current_rom), "w");
  f.println("Default ROM\n");

  if (SPIFFS.exists("/wifi.conf")) {
    Serial.print("Found wifi config");
    if(connectBadge()) {
      pullNotifications();
    }
    mainMenu->addMenuItem(new MenuItem("Badge", []() {
      FullScreenBMPDisplay* badge_screen = new FullScreenBMPDisplay();
      badge_screen->setBmp("/badge.bmp");
      ui->open(badge_screen);
    }));
    mainMenu->addMenuItem(new MenuItem("Notifications", []() {
      Menu * notificationMenu = new Menu();
      notificationMenu->addMenuItem(new MenuItem("Back", []() {
        ui->closeCurrent();
      }));
      NotificationIterator notit(NotificationFilter::ACTIVE);
      while (notit.next()) {
        Notification noti = notit.getNotification();
        NotificationHandle notiHandl = notit.getHandle();
        notificationMenu->addMenuItem(new MenuItem(noti.summary, [notiHandl]() {
          Notification handNot;
          if(getNotificationByHandle(notiHandl, &handNot)) {
            ui->open(new NotificationScreen(handNot.summary, handNot.location, handNot.description));
          } else {
            ui->open(new NotificationScreen("Error", "", "Notification does not exist anymore."));
          }
        }));
      }
      ui->open(notificationMenu);
    }));
    mainMenu->addMenuItem(new MenuItem("Configuration", []() {
      Menu * configMenu = new Menu();
      configMenu->addMenuItem(new MenuItem("Back", []() {
            ui->closeCurrent();
      }));
      MenuItem * themeItem = new MenuItem("Theme: "+getConfig("theme", DEFAULT_THEME), []() {});
      themeItem->setTrigger([themeItem]() {
       String current = getConfig("theme", DEFAULT_THEME); 
       autoTheme = false;
       if(current == "Light") {
        setConfig("theme", "Dark");
        ui->setTheme(new ThemeDark());
        isDark = true;
       } else if(current == "Dark") {
        setConfig("theme", "Auto");
        autoTheme = true;
       } else {
        isDark = false;
        ui->setTheme(new ThemeLight());
        setConfig("theme", "Light");
       }
       themeItem->setText("Theme: "+getConfig("theme", DEFAULT_THEME));
       });
      configMenu->addMenuItem(themeItem);

      MenuItem * wifiLightItem = new MenuItem("WifiLight: "+getConfig("wifilight", "255"), []() {});
      wifiLightItem->setTrigger([wifiLightItem]() {
       String current = getConfig("wifilight", "255"); 
       if (current == "0") {
        setConfig("wifilight", "255");
       } else if(current == "255") {
        setConfig("wifilight", "100");
       } else if(current == "100") {
        setConfig("wifilight", "50");
       } else if(current == "50") {
        setConfig("wifilight", "10");
       } else {
        setConfig("wifilight", "0");
       }
       wifiLightItem->setText("WifiLight: "+getConfig("wifilight", "255"));
       wifiLight = atoi(getConfig("wifilight", "255").c_str());
       });
      configMenu->addMenuItem(wifiLightItem);

      MenuItem * ennotifItem= new MenuItem("Notifications: "+getConfig("ennotif", "on"), []() {});
      ennotifItem->setTrigger([ennotifItem]() {
       String current = getConfig("ennotif", "on"); 
       if (current == "on") {
        setConfig("ennotif", "off");
       }  else {
        setConfig("ennotif", "on");
       }
       ennotifItem->setText("Notifications: "+getConfig("ennotif", "on"));
       ennotif = getConfig("ennotif", "on") == "on";
       });
      configMenu->addMenuItem(ennotifItem);
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

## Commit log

2017-01-10 ADD: first design files for to badge
    [cpu.SchDoc, gpio.SchDoc, power.SchDoc]
2017-01-18 ADD: 3D models, fabrication output for first prototype
    [cpu.SchDoc, fabrication.PcbDoc, gpio.SchDoc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]
2017-02-26 Added CAD-Files and the alkohol-sensor-sketch
    [Alkoholsensor.scad, Alkoholsensor.stl, baukloetzchen.scad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]
2017-03-04 Fixed sketch for use with the badge
    [alkoholsensor.ino]
2017-03-05 moved CAD files
    [Alkoholsensor.scad, Alkoholsensor.stl, baukloetzchen.scad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]
2017-03-05 moved some files
    [Alkoholsensor.scad, Alkoholsensor.stl, baukloetzchen.scad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]
2017-03-19 ADD: rev 2.0 hardware designs
    [cpu.SchDoc, fabrication.PcbDoc, gpio.SchDoc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]
2017-03-22 refined scad model
    [Alkoholsensor.scad]
2017-03-23 UPD: design files for rev. 2.0
    [cpu.SchDoc, gpio.SchDoc, power.SchDoc]
2017-04-21 ADD: gerber files
    [gpn-badge_Copper_Signal_Bot.gbr, gpn-badge_Copper_Signal_Top.gbr, gpn-badge_Drawing_1.gbr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]
2017-04-22 ADD: framebuffer example
2017-04-30 ADD: pnp file
    [Pick Place for gpn-badge.csv]
2017-04-30 UPD: reverse polarity protection
    [Pick Place for gpn-badge.csv, Pick Place for gpn_panel.csv]
2017-05-04 ADD: GPN-Badge compatible arduino toolchain
    [rgisters_dump.txt]
2017-05-04 UPD: bootloader
    [cpu.SchDoc, fabrication.PcbDoc, gpio.SchDoc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]
2017-05-04 UPD: recompile rboot for DIO SPI
2017-05-04 UPD: different memorymap, now with 6x 512kB slots and 1M SPIFFS. Also added rboot-api support to the arduino toolchain
2017-05-10 ADD: experimental eagle version
    [cpu.sch, gpio.sch, power.sch]
2017-05-10 ADD: final altium design
    [cpu.SchDoc, gpio.SchDoc, gpn-badge.PrjPcb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]
2017-05-11 fixed sketch for Badge V2.0
    [alkoholsensor.ino]
2017-05-21 UPD: more understandable Flash Slot description
2017-05-25 FIX: use dynamic json buffer
    [default-rom.ino]
2017-05-25 FIX: only allocate download buffer once
    [default-rom.ino]
2017-05-25 UPD: get rid of the arduinoJson lib
2017-05-25 ADD: switch between pw and ssid display on joystick interaction
2017-05-25 UPD: filter unsupported enc types
2017-05-25 ADD: debug output for heap analysis ADD: connect api function (not fully working) UPD: Use rboot UPD: use printf for json generation
2017-05-25 FIX: turn off leds after connect
    [default-rom.ino]
2017-05-25 ADD: url encoder/writer
2017-05-25 Verify fingerprint
2017-05-25 FIX: correct file mode for status update
    [notification_db.cpp]
2017-05-25 FIX: disconnect wifi before initialConfig
    [default-rom.ino]
2017-05-25 ADD: env-light dependent theme switch
2017-05-25 CLN: WTF ARDUINO IDE??!
2017-05-25 UPD: #define pull interval and shorten it in #debug mode
    [default-rom.ino]
2017-05-25 FIX: let the leds some time before they are turned off
    [default-rom.ino]
2017-05-25 UPD: stronger averaging for battery value
2017-05-25 FIX: correct config save/default create check
    [default-rom.ino]
2017-05-25 Share: send more often, led
2017-05-25 Added sensor rom
2017-05-25 Readme: Framebuffer define
2017-05-26 gpnbadge package does not pretend to be an update for standard esp8266 repo any more; updated zip to 2.4.0 version from https://public.electronics.fail/
    [rgisters_dump.txt]
2017-05-26 Change Arduino url to repo
2017-05-26 Really fix the board ZIP URL now ;-)

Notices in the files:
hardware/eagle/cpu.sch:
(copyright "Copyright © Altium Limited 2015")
